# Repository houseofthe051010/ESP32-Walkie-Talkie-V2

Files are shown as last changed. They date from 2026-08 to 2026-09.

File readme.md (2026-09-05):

# ESP32 Walkie Talkie V2

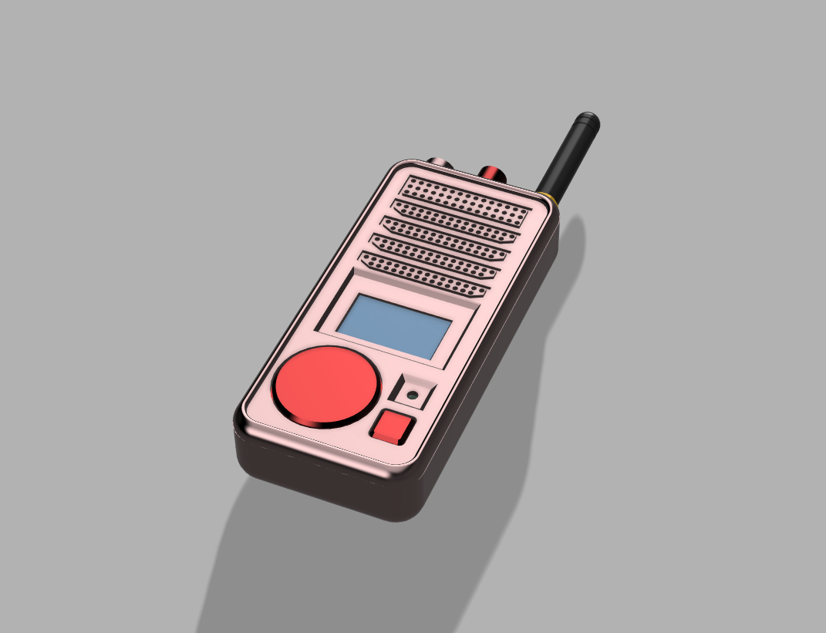
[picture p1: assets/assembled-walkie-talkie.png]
Fully assembled walkie-talkie design


This project is submitted to review at forge; And also, I have made a similar ESP32 based walkie talkie in the past. This is an iteration and is significantly different from the old version. It uses a custom PCB, new and different components, communication protocols, radios, and CAD/casing. It is a much needed iteration from my old version which was very difficult to hard wire and prone to several mistakes.

## Instructions

Build instructions are at: [instructions.md](instructions.md)

## Why this project exists

I made this projet not because I just wanted a walkie talkie, I wanted a control interface for my other projects. Not only can I use this board as a walkie talkie, I can use it in my other projects for other types of communications as the PCB is basically a built in radio system, which I can connect to another system using uart and use it for several other purposes. It has a LORA SX1262 radio, with 5-10km range, but at the same time has a ESP32 with WIFI+BLUETOOTH. I can use this for IoT long distance, and connect wifi/bluetooth devices and extend their range significantly using the radio. This is different from walkie talkies already out there.

## Features

- Can be used for IOT (Wifi + Bluetooth) long distance when paired with the 915mhz radio
- 5 Buttons to do multiple things 
- Exposed pins to connect pheripherals, such as an IMU
- ICS-43432 I2S microphone, MAX98753A amplifier, SSD1306 0.96" OLED, SX1262 RADIO, ESP32WROOM32-16
- Potentiometer, battery charge detection, TP4056 charging, 2000MAH Lipo, 10H batery life

## Hardware

In the Schematics folder is the GERBER+BOM+CPL file for easy PCBA assembly of this board. The KiCad project is also there.

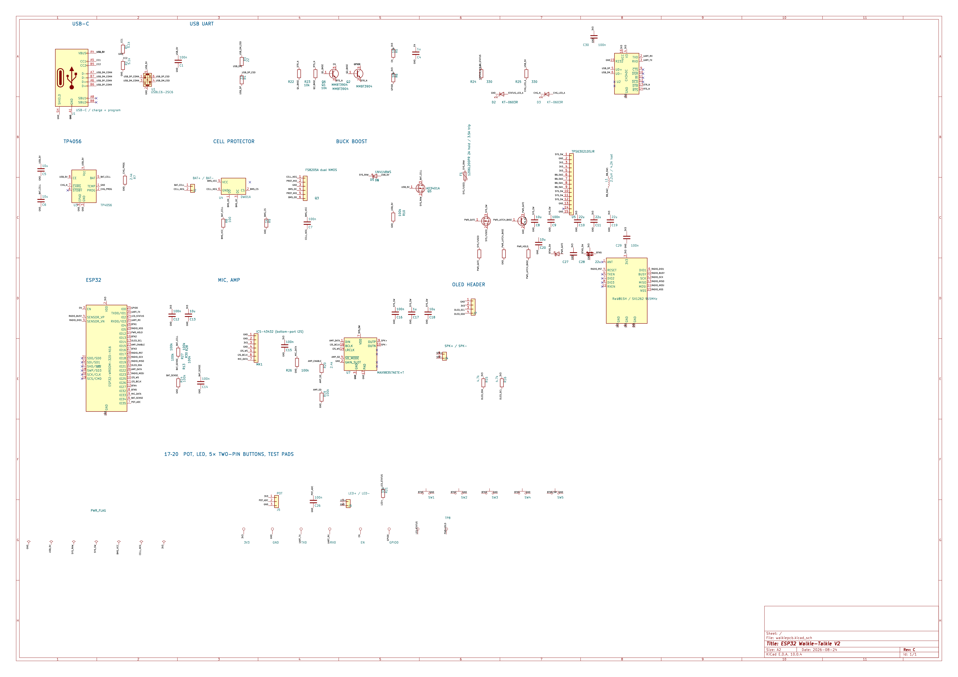
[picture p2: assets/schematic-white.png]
Walkie-talkie schematic


## Firmware

I have included a basic micropython test file for using the walkie talkie when assembled with its radio. It is just a prototype and not complete. I will likely make a full firmware by porting it from my old walkie talkie build and using it as a tempalte.

## Project BOM

| Item | Qty/walkie | Pack | Pack price | Per piece | Cost/walkie | Source / note |
|---|---:|---:|---:|---:|---:|---|
| Assembled walkie-talkie PCB | 1 | 5 | $167.97 | $33.5940 | $33.5940 | [Five-PCBA quote](assets/jlc-quote-5-pcba.png); includes PCB components assembly |
| 0.96-inch SSD1306 I2C OLED | 1 | 5 | $8.83 | $1.7660 | $1.7660 | [AliExpress OLED](https://www.aliexpress.us/item/3256805954920554.html) |
| 804050 2000 mAh 3.7 V LiPo | 1 | 4 | $16.60 | $4.1500 | $4.1500 | [AliExpress battery pack](https://www.aliexpress.us/item/3256812605593313.html)|
| 915 MHz 2 dBi antenna with I-PEX/U.FL lead | 1 | 4 | $5.66 | $1.4150 | $1.4150 | [AliExpress antenna](https://www.aliexpress.us/item/3256805050972049.html)|
| 6 × 6 × 5 mm tactile push button | 5 | 50 | $1.28 | $0.0256 | $0.1280 | [AliExpress button pack](https://www.aliexpress.us/item/3256805859865632.html) |
| 0.5 W ultra-slim speaker | 1 | 5 | $2.43 | $0.4860 | $0.4860 | [AliExpress speaker](https://www.aliexpress.us/item/3256809614775479.html) |
| 20 kΩ panel potentiometer | 1 | 5 | $1.86 | $0.3720 | $0.3720 | [AliExpress potentiometer](https://www.aliexpress.us/item/2255799926052367.html) |
| Printed Casing, Wires, and Screws | 1 Set | 1 | $0 | $0 | $0 | Use available filament, wire and m3 screws or glue. |
| 650 nm 5 mW laser module | 1 | 10 | $2.83 | $0.2830 | $0.2830 | [AliExpress laser module](https://www.aliexpress.us/item/3256806548478140.html) |
| **Complete cost per walkie-talkie** |  |  |  |  | **$42.1940 (~$42.19)** | Per-unit|

### What I would do differently in the future / future plans

- I would make it thinner
- Use more dense parts for smaller size (with a stronger budget)
- Make it fully waterproof

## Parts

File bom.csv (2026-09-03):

Category | Item | Quantity per Walkie | Pack Quantity | Pack Price USD | Price per Piece USD | Cost per Walkie USD | Source URL | Notes
PCB | Assembled walkie-talkie PCB | 1 | 5 | 167.97 | 33.5940 | 33.5940 | assets/jlc-quote-5-pcba.png | Five-PCBA quote includes 163.97 assembly plus 4.00 PCB fabrication; excludes shipping and tax
Display | 0.96-inch SSD1306 I2C OLED module | 1 | 5 | 8.83 | 1.7660 | 1.7660 | https://www.aliexpress.us/item/3256805954920554.html | Verify the ordered variant uses the required four-pin I2C interface and pin order
Power | 804050 2000 mAh 3.7 V 1S LiPo | 1 | 4 | 16.60 | 4.1500 | 4.1500 | https://www.aliexpress.us/item/3256812605593313.html | Verify actual dimensions lead polarity discharge rating and protection before installation
RF | 915 MHz 2 dBi antenna with I-PEX/U.FL lead | 1 | 4 | 5.66 | 1.4150 | 1.4150 | https://www.aliexpress.us/item/3256805050972049.html | Use one antenna per walkie; verify 915 MHz tuning and connector compatibility before transmitting
Controls | 6 x 6 x 5 mm tactile push button | 5 | 50 | 1.28 | 0.0256 | 0.1280 | https://www.aliexpress.us/item/3256805859865632.html | Five buttons required per walkie
Audio | 0.5 W ultra-slim speaker | 1 | 5 | 2.43 | 0.4860 | 0.4860 | https://www.aliexpress.us/item/3256809614775479.html | Verify the purchased impedance is 4-8 ohms and confirm enclosure fit
Controls | 20 kohm panel potentiometer | 1 | 5 | 1.86 | 0.3720 | 0.3720 | https://www.aliexpress.us/item/2255799926052367.html | Connect the ends to 3V3 and GND and the wiper to POT_ADC
Assembly | Printed Casing, Wires, and Screws | 1 Set | 1 | 0 | 0 | 0 |  | Use available filament, wire and m3 screws or glue.
Accessory | 650 nm 5 mW laser module | 1 | 10 | 2.83 | 0.2830 | 0.2830 | https://www.aliexpress.us/item/3256806548478140.html | One laser module per walkie; user-supplied pack price
TOTAL | Complete cost per walkie | 1 | N/A | N/A | N/A | 42.1940 |  | Per-walkie allocated parts cost using the five-PCBA quote; excludes shipping and tax

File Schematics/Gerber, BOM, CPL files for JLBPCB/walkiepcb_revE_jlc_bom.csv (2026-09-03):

Comment | Designator | Footprint | LCSC Part #
100n | C1,C7,C9,C12,C14,C15,C16,C26,C29,C30 | Capacitor_SMD:C_0603_1608Metric | C14663
1u | C4,C17 | Capacitor_SMD:C_0603_1608Metric | C15849
10u | C5,C6,C8,C13,C18,C20 | Capacitor_SMD:C_0805_2012Metric | C15850
22u | C10,C11,C19,C27,C28 | Capacitor_SMD:C_0805_2012Metric | C45783
SS34 | D1 | Diode_SMD:D_SMA | C8678
KT-0603R | D2,D3 | LED_SMD:LED_0603_1608Metric | C2286
1N4148WS | D5,D6 | Diode_SMD:D_SOD-323 | C2128
1206L200PR 2A hold / 3.5A trip | F1 | Fuse:Fuse_1206_3216Metric | C151163
USB-C / charge + program | J1 | Connector_USB:USB_C_Receptacle_HRO_TYPE-C-31-M-12 | C165948
2.2uH / 4.2A Isat | L1 | Inductor_SMD:L_Murata_DFE201610P | C6807735
ICS-43432 (bottom-port I2S) | MK1 | walkiepcb:ICS-43432_LGA7_4x3mm | C574021
MMBT3904 | Q1,Q2,Q6 | Package_TO_SOT_SMD:SOT-23 | C20526
FS8205A dual NMOS | Q3 | Package_TO_SOT_SMD:SOT-23-6 | C908265
AO3401A | Q4,Q5 | Package_TO_SOT_SMD:SOT-23 | C15127
5.1k | R1,R2 | Resistor_SMD:R_0603_1608Metric | C23186
22 | R3,R4 | Resistor_SMD:R_0603_1608Metric | C23345
10k | R5,R6,R22,R23 | Resistor_SMD:R_0603_1608Metric | C25804
2.4k | R7,R20 | Resistor_SMD:R_0603_1608Metric | C22940
100 | R8 | Resistor_SMD:R_0603_1608Metric | C22775
1k | R9 | Resistor_SMD:R_0603_1608Metric | C21190
100k | R10,R13,R14,R19 | Resistor_SMD:R_0603_1608Metric | C25803
4.7k | R15,R16 | Resistor_SMD:R_0603_1608Metric | C23162
330 | R21,R24,R25 | Resistor_SMD:R_0603_1608Metric | C23138
100k | R26,R27,R28,R30 | Resistor_SMD:R_0402_1005Metric | C25741
USBLC6-2SC6 | U1 | Package_TO_SOT_SMD:SOT-23-6 | C7519
CH340C | U2 | Package_SO:SOIC-16_3.9x9.9mm_P1.27mm | C7464026
TP4056-42-ESOP8 | U3 | Package_SO:SOIC-8-1EP_3.9x4.9mm_P1.27mm_EP2.41x3.3mm | C16581
DW01A | U4 | Package_TO_SOT_SMD:SOT-23-6 | C351410
TPS63021DSJR | U5 | Package_DFN_QFN:DFN-14-1EP_3x4mm_P0.5mm_EP1.7x3.3mm | C202140
ESP32-WROOM-32D-N16 | U6 | RF_Module:ESP32-WROOM-32 | C529578
MAX98357AETE+T | U7 | Package_DFN_QFN:TQFN-16-1EP_3x3mm_P0.5mm_EP1.23x1.23mm | C910544
Ra-01SH / SX1262 915MHz | U8 | walkiepcb:Ai-Thinker_Ra-01SH | C2764087

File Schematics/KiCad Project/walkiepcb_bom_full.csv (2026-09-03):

Reference | Value | Footprint | Manufacturer | MPN | JLC/LCSC | JLC Classification | Economic Compatible | DNP | Notes | QUANTITY
C1,C7,C9,C12,C14-C16,C26,C29,C30 | 100n | Capacitor_SMD:C_0603_1608Metric | YAGEO | CC0603KRX7R9BB104 | C14663 | Basic | YES | NO | ADC acquisition reservoir; 5ms Thevenin RC,Buck-boost VINA bypass; place at VINA/GND,Connector-local VBUS bypass,DW01 supply filter,ESP32 local HF bypass,ICS-43432 local bypass; place directly between VDD and GND,MAX98357A local bypass,Potentiometer ADC filter,Ra-01SH/CH340C local high-frequency decoupling | 10
C4,C17 | 1u | Capacitor_SMD:C_0603_1608Metric | Samsung Electro-Mechanics | CL10A105KB8NNNC | C15849 | Basic | YES | NO | ESP32 EN power-on delay,MAX98357A local mid-band bypass | 2
C5,C6,C8,C13,C18,C20 | 10u | Capacitor_SMD:C_0805_2012Metric | Samsung Electro-Mechanics | CL21A106KAYNNNE | C15850 | Basic | YES | NO | Buck-boost input capacitor 2; TPS63021 reference design uses 2x10uF at VIN/PGND,Buck-boost input capacitor; place at VIN/PGND,ESP32 local bulk,MAX98357A local bulk,TP4056 battery bypass,TP4056 input bulk | 6
C10,C11,C19,C27,C28 | 22u | Capacitor_SMD:C_0805_2012Metric | Samsung Electro-Mechanics | CL21A226MAQNNNE | C45783 | Basic | YES | NO | Ra-01SH local bulk decoupling,TPS63021 output capacitor 1; place at VOUT/PGND,TPS63021 output capacitor 2; place at VOUT/PGND,TPS63021 output capacitor 3; 66uF nominal bank follows TI stability matrix | 5
D1 | SS34 | Diode_SMD:D_SMA | MDD | SS34 | C8678 | Basic | YES | NO | USB-to-system Schottky; anode USB, cathode SYS_RAW | 1
D2,D3 | KT-0603R | LED_SMD:LED_0603_1608Metric | Hubei KENTO | KT-0603R | C2286 | Basic | YES | NO | On-board status LED,TP4056 charging indicator; on while charging | 2
D5,D6 | 1N4148WS | Diode_SMD:D_SOD-323 | Jiangsu Changjing Electronics Technology | 1N4148WS | C2128 | Basic | YES | NO | BTN5 sense diode; A=BTN5 K=BTN5_SW,BTN5 start diode; A=PWR_GATE K=BTN5_SW | 2
F1 | 1206L200PR 2A hold / 3.5A trip | Fuse:Fuse_1206_3216Metric | Littelfuse | 1206L200PR | C151163 | Extended | YES | NO | Resettable system fault protection | 1
J1 | USB-C / charge + program | Connector_USB:USB_C_Receptacle_HRO_TYPE-C-31-M-12 | Korean Hroparts Elec | TYPE-C-31-M-12 | C165948 | Extended | YES | NO | USB 2.0 sink; shell grounded | 1
J2 | BAT+ / BAT- | walkiepcb:WirePads_2_P5.08mm | Hand-wired | 2 solder pads |  | DNP | YES | YES | Battery wires; BAT- is cell negative before protection FETs | 1
J4 | SPK+ / SPK- | walkiepcb:WirePads_2_P5.08mm | Hand-wired | 2 solder pads |  | DNP | YES | YES | Differential Class-D output; neither terminal is ground | 1
J5 | 3V3 / POT_ADC / GND | walkiepcb:WirePads_3_P2.54mm | Hand-wired | 3 solder pads |  | DNP | YES | YES | External potentiometer; exactly three holes | 1
J6 | LED+ / LED- | walkiepcb:WirePads_2_P2.54mm | Hand-wired | 2 solder pads |  | DNP | YES | YES | External LED; exactly two holes | 1
J7 | OLED MODULE: GND / 3V3 / SCL / SDA | walkiepcb:OLED_1x04_P2.54mm_HolesOnly | Hand-wired | 2.54mm 1x4 header |  | DNP | YES | YES | For a commercial SSD1306 I2C module; verify the module pin order before wiring | 1
L1 | 2.2uH / 4.2A Isat | Inductor_SMD:L_Murata_DFE201610P | Sunlord | MWTC201610S2R2MT | C6807735 | Extended | YES | NO | 123mohm; 2.3A Irms; 4.2A Isat; buck-boost energy-transfer inductor | 1
MK1 | ICS-43432 (bottom-port I2S) | walkiepcb:ICS-43432_LGA7_4x3mm | TDK InvenSense | ICS-43432 | C574021 | Extended | YES | NO | Economic-compatible but high-difficulty assembly; stocked bottom-port I2S microphone | 1
Q1,Q2,Q6 | MMBT3904 | Package_TO_SOT_SMD:SOT-23 | CJ (Changjiang Electronics Tech) | MMBT3904 | C20526 | Basic | YES | NO | CH340C DTR/RTS automatic-programming transistor,Firmware-controlled main-gate pull-down | 3
Q3 | FS8205A dual NMOS | Package_TO_SOT_SMD:SOT-23-6 | FUXINSEMI | FS8205A | C908265 | Extended | YES | NO | Back-to-back common-drain battery-protection MOSFET; verified FUXINSEMI pinout | 1
Q4,Q5 | AO3401A | Package_TO_SOT_SMD:SOT-23 | Alpha & Omega Semiconductor | AO3401A | C15127 | Basic | YES | NO | Main soft-power high-side P-MOSFET; S=SYS_FUSED D=SYS_SW,P-channel ideal battery path; S=SYS_RAW D=BAT_CELL | 2
R1,R2 | 5.1k | Resistor_SMD:R_0603_1608Metric | UNI-ROYAL | 0603WAF5101T5E | C23186 | Basic | YES | NO | USB-C Rd | 2
R3,R4 | 22 | Resistor_SMD:R_0603_1608Metric | UNI-ROYAL | 0603WAF220JT5E | C23345 | Basic | YES | NO | USB D+ series termination; place near CH340C,USB D- series termination; place near CH340C | 2
R5,R6,R22,R23 | 10k | Resistor_SMD:R_0603_1608Metric | UNI-ROYAL | 0603WAF1002T5E | C25804 | Basic | YES | NO | CH340C automatic-programming transistor base resistor,ESP32 EN pull-up,ESP32 boot pull-up | 4
R7,R20 | 2.4k | Resistor_SMD:R_0603_1608Metric | UNI-ROYAL | 0603WAF2401T5E | C22940 | Basic | YES | NO | Limits SD_MODE clamp current if raw VDD falls below 3V3,Sets TP4056 current ≈500mA | 2
R8 | 100 | Resistor_SMD:R_0603_1608Metric | UNI-ROYAL | 0603WAF1000T5E | C22775 | Basic | YES | NO | DW01 supply filter | 1
R9 | 1k | Resistor_SMD:R_0603_1608Metric | UNI-ROYAL | 0603WAF1001T5E | C21190 | Basic | YES | NO | DW01 current-sense input filter | 1
R10,R13,R14,R19 | 100k | Resistor_SMD:R_0603_1608Metric | UNI-ROYAL | 0603WAF1003T5E | C25803 | Basic | YES | NO | Battery divider lower,Battery divider upper,Keeps amplifier shut down during boot,PMOS gate pull-down | 4
R15,R16 | 4.7k | Resistor_SMD:R_0603_1608Metric | UNI-ROYAL | 0603WAF4701T5E | C23162 | Basic | YES | NO | I2C pull-up | 2
R21,R24,R25 | 330 | Resistor_SMD:R_0603_1608Metric | UNI-ROYAL | 0603WAF3300T5E | C23138 | Basic | YES | NO | Indicator current limit; reuses existing Basic BOM line,≈3.9mA for 2.0V LED at 3.3V | 3
R26-R28,R30 | 100k | Resistor_SMD:R_0402_1005Metric | UNI-ROYAL | 0402WGF1003TCE | C25741 | Basic | YES | NO | GPIO12 hold base-current limit,ICS-43432 SD pulldown required while microphone output is tri-stated,Latch-transistor base pull-down,Main P-MOS gate pull-up | 4
SW1 | BTN1 / hand-solder | walkiepcb:SW_Tactile_2Pin_6x6mm_P5.0mm | E-Switch or equivalent | TL1100F100QG |  | DNP | YES | YES | Exactly two plated holes; ESP32 internal pull-up | 1
SW2 | BTN2 / hand-solder | walkiepcb:SW_Tactile_2Pin_6x6mm_P5.0mm | E-Switch or equivalent | TL1100F100QG |  | DNP | YES | YES | Exactly two plated holes; ESP32 internal pull-up | 1
SW3 | BTN3 / hand-solder | walkiepcb:SW_Tactile_2Pin_6x6mm_P5.0mm | E-Switch or equivalent | TL1100F100QG |  | DNP | YES | YES | Exactly two plated holes; ESP32 internal pull-up | 1
SW4 | BTN4 / hand-solder | walkiepcb:SW_Tactile_2Pin_6x6mm_P5.0mm | E-Switch or equivalent | TL1100F100QG |  | DNP | YES | YES | Exactly two plated holes; ESP32 internal pull-up | 1
SW5 | BTN5 POWER / FUNCTION | walkiepcb:SW_Tactile_2Pin_6x6mm_P5.0mm | E-Switch or equivalent | TL1100F100QG |  | DNP | YES | YES | Hold 2 s for firmware-validated power on/off; pulls PWR_GATE low | 1
TP1 | 3V3 | walkiepcb:TestPad_1.0mm | PCB pad | SMD test pad |  | PCB | YES | YES | Probe-only test pad | 1
TP2 | GND | walkiepcb:TestPad_1.0mm | PCB pad | SMD test pad |  | PCB | YES | YES | Probe-only test pad | 1
TP3 | TX0 | walkiepcb:TestPad_1.0mm | PCB pad | SMD test pad |  | PCB | YES | YES | Probe-only test pad | 1
TP4 | RX0 | walkiepcb:TestPad_1.0mm | PCB pad | SMD test pad |  | PCB | YES | YES | Probe-only test pad | 1
TP5 | EN | walkiepcb:TestPad_1.0mm | PCB pad | SMD test pad |  | PCB | YES | YES | Probe-only test pad | 1
TP6 | GPIO0 | walkiepcb:TestPad_1.0mm | PCB pad | SMD test pad |  | PCB | YES | YES | Probe-only test pad | 1
TP7 | LED_STATUS | walkiepcb:TestPad_1.0mm | PCB pad | SMD test pad |  | PCB | YES | YES | Optional expansion solder/test pad | 1
TP8 | PWR_HOLD / GPIO12 | walkiepcb:TestPad_1.0mm | PCB pad | SMD test pad |  | PCB | YES | YES | Soft-power hold output and diagnostic pad; GPIO12 boot strap | 1
U1 | USBLC6-2SC6 | Package_TO_SOT_SMD:SOT-23-6 | STMicroelectronics | USBLC6-2SC6 | C7519 | Extended | YES | NO | Low-capacitance USB ESD | 1
U2 | CH340C | Package_SO:SOIC-16_3.9x9.9mm_P1.27mm | WCH | CH340C | C7464026 | Extended | YES | NO | Crystal-less USB-UART; VCC and V3 tied to switched 3V3; main switch must be ON for USB programming | 1
U3 | TP4056-42-ESOP8 | Package_SO:SOIC-8-1EP_3.9x4.9mm_P1.27mm_EP2.41x3.3mm | Top Power ASIC | TP4056-42-ESOP8 | C16581 | Extended | YES | NO | RPROG 2.4k gives nominal 500mA; EP grounded | 1
U4 | DW01A | Package_TO_SOT_SMD:SOT-23-6 | PUOLOP | DW01A | C351410 | Extended | YES | NO | 1S protector; 4.3V overcharge / 2.5V overdischarge; deep-discharge cutoff is safety backup | 1
U5 | TPS63021DSJR | Package_DFN_QFN:DFN-14-1EP_3x4mm_P0.5mm_EP1.7x3.3mm | Texas Instruments | TPS63021DSJR | C202140 | Extended | YES | NO | Fixed 3.3V synchronous buck-boost; pin15 models exposed PGND pad; PS/SYNC low = power-save; EN tied VIN | 1
U6 | ESP32-WROOM-32D-N16 | RF_Module:ESP32-WROOM-32 | Espressif Systems | ESP32-WROOM-32D-N16 | C529578 | Extended | YES | NO | 16MB flash; PCB antenna; CH340C UART programming | 1
U7 | MAX98357AETE+T | Package_DFN_QFN:TQFN-16-1EP_3x3mm_P0.5mm_EP1.23x1.23mm | Analog Devices / Maxim | MAX98357AETE+T | C910544 | Extended | YES | NO | 12dB fixed gain; left channel; EP grounded | 1
U8 | Ra-01SH / SX1262 915MHz | walkiepcb:Ai-Thinker_Ra-01SH | Ai-Thinker | Ra-01SH | C2764087 | Extended | YES | NO | SX1262; 803-930MHz; integrated I-PEX socket; +22dBm | 1

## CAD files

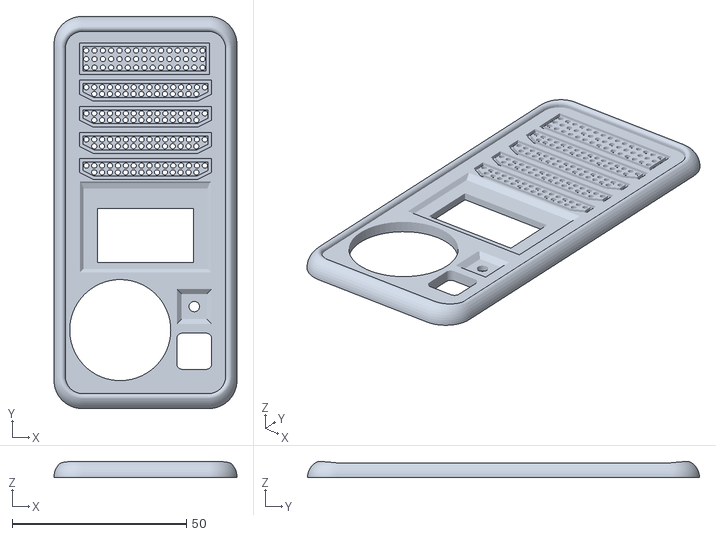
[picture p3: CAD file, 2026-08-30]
CAD/3d Printable STLs/Case Lid.stl
52.5 x 112.5 x 4.66

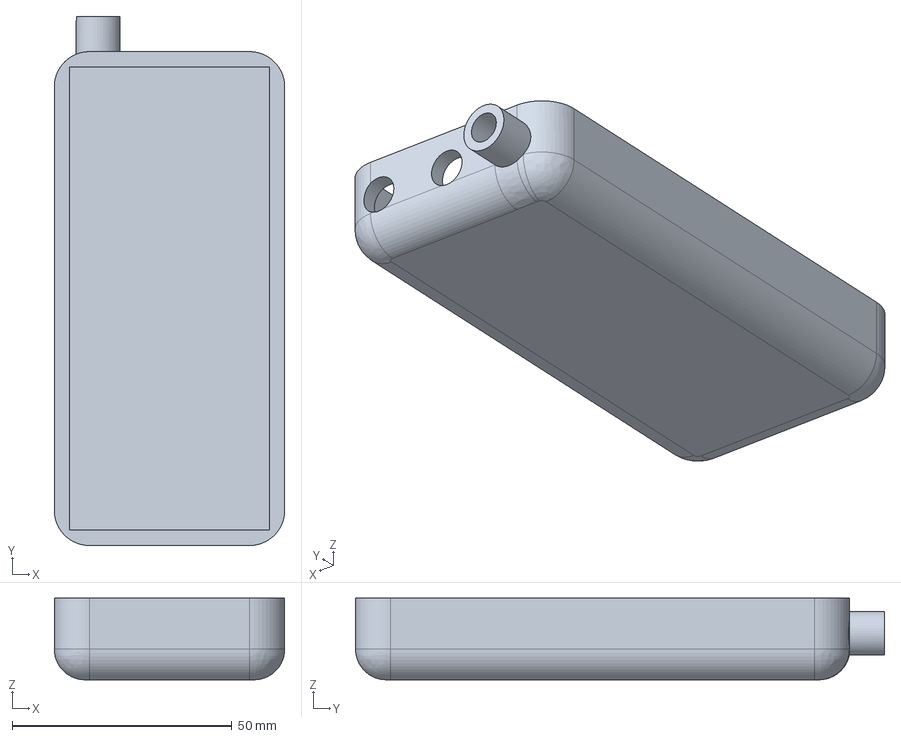
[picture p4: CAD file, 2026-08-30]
CAD/Individual STEP Files/Case Bottom.step
52.5 x 120.5 x 18.6 mm

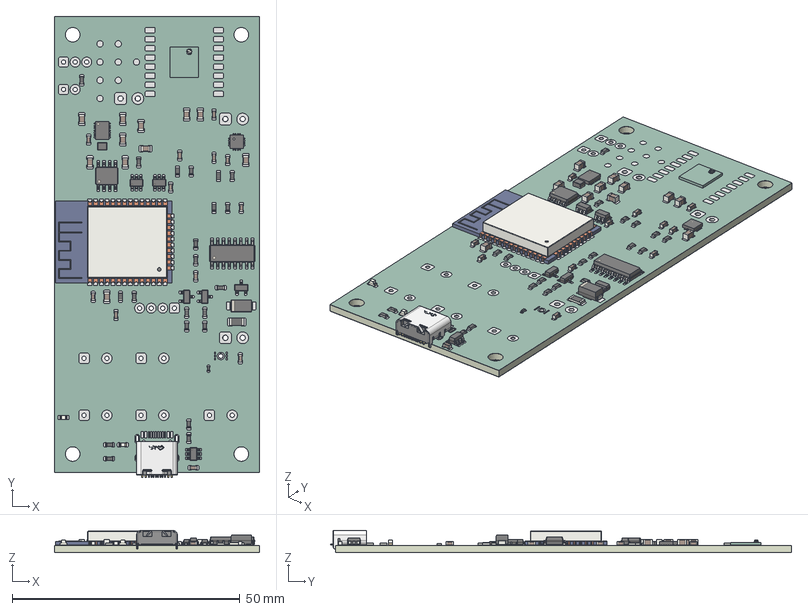
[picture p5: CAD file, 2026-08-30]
CAD/PCB/walkiepcb_final.step
45.0 x 101.1 x 4.90 mm
R_0603_1608Metric x 21
SOT-23 x 3
C_0603_1608Metric x 12
ESP32-WROOM-32
L_Murata_DFE201610P
SOT-23-6 x 3
Fuse_1206_3216Metric
LED_0603_1608Metric x 2
C_0805_2012Metric x 11
D_SMA
SOIC-16_3.9x9.9mm_P1.27mm
USB-C_SMD-TYPE-C-31-M-12
R_0402_1005Metric
U.FL_Hirose_U.FL-R-SMT-1_Vertical
Ra-01SH_step_source_PCB
SOIC-8-1EP_3.9x4.9mm_P1.27mm_EP2.41x3.81mm
TQFN_16_1EP_3x3mm_P05mm_EP16x16mm
DFN-14-1EP_3x4mm_Pitch0.5mm
walkiepcb_step_export_copper
walkiepcb_step_export_pad
walkiepcb_step_export_via
walkiepcb_step_export_soldermask x 2
walkiepcb_step_export_PCB

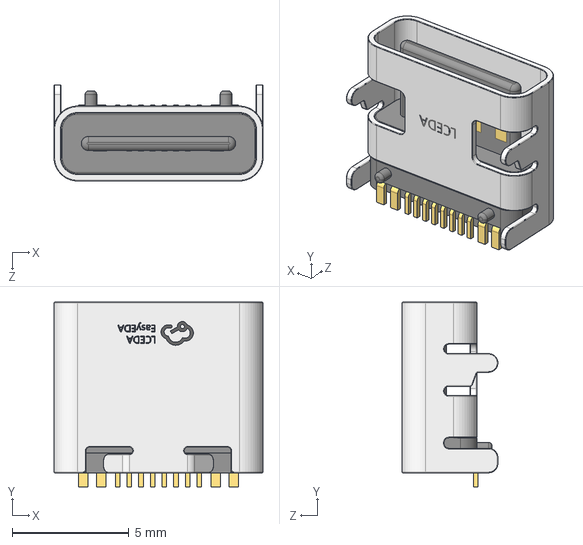
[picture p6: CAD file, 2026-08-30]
Schematics/KiCad Project/3d/USB-C_SMD-TYPE-C-31-M-12.step
8.94 x 7.90 x 4.10 mm

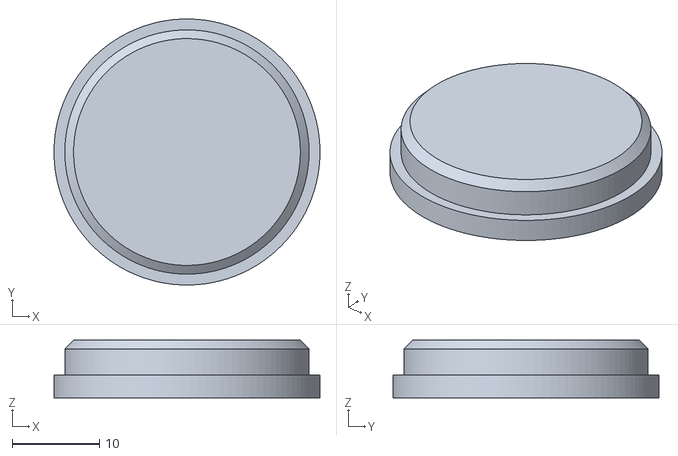
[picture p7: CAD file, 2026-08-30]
CAD/3d Printable STLs/Button Pad.stl
30.5 x 30.5 x 6.60

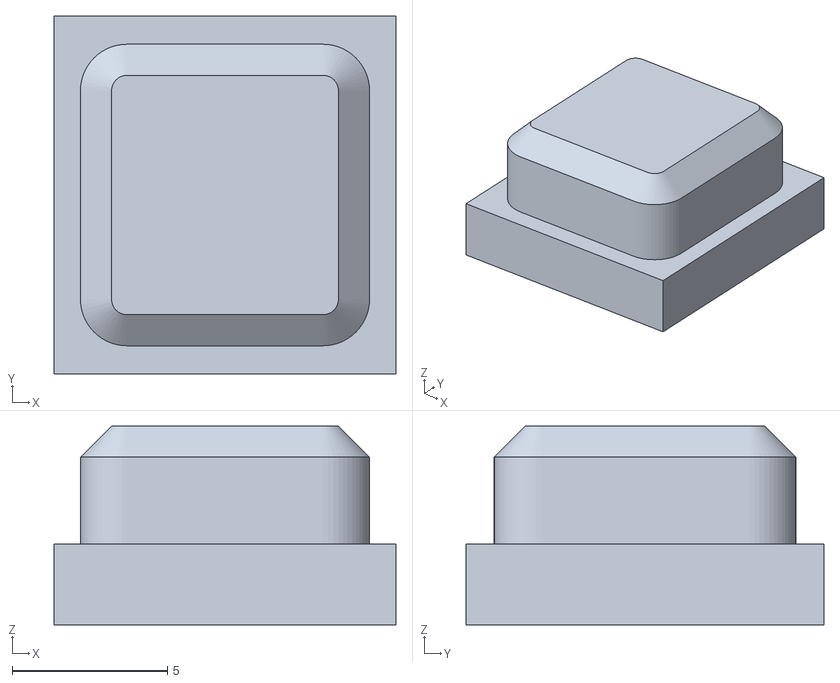
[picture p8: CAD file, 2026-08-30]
CAD/3d Printable STLs/Button Press.stl
11.0 x 11.5 x 6.40

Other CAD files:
CAD/Assembly/Walkie Talkie V2.step
CAD/3d Printable STLs/Case Bottom.stl
CAD/Individual STEP Files/Case Lid.step
CAD/Individual STEP Files/Button Pad.step
CAD/Individual STEP Files/Button Press.step
CAD/Assembly/Walkie Talkie V2 PCB.f3z

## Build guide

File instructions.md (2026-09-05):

# Walkie Talkie Instructions

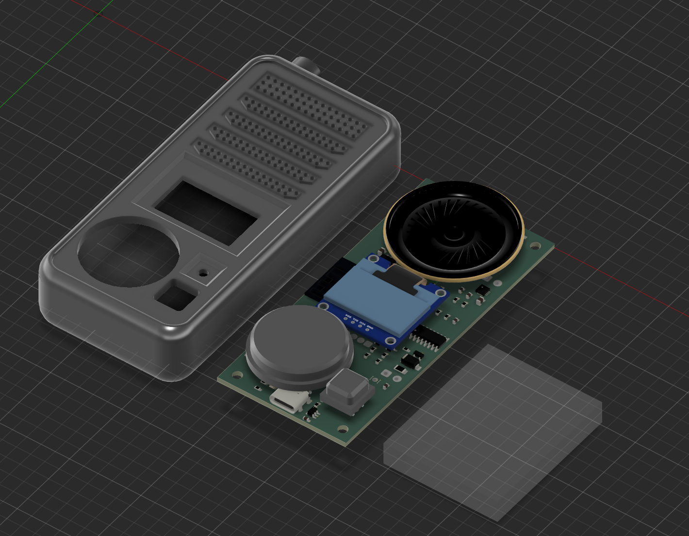
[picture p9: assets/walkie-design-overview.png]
Walkie-talkie enclosure and PCB design


1. You must get the lipo battery and solder its wires to the input of the pcb

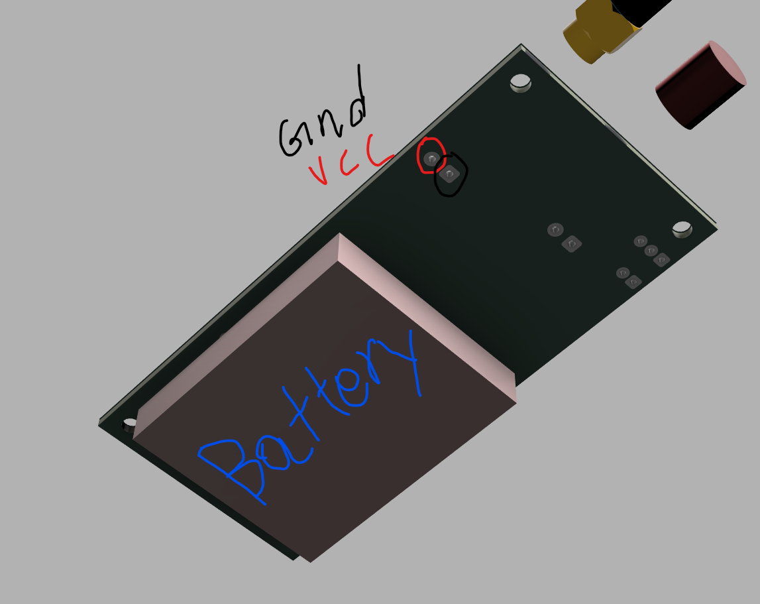
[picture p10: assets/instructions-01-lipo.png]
Lipo battery connected to the PCB


2. Then, solder all 5 buttons using the through holes in the pcb

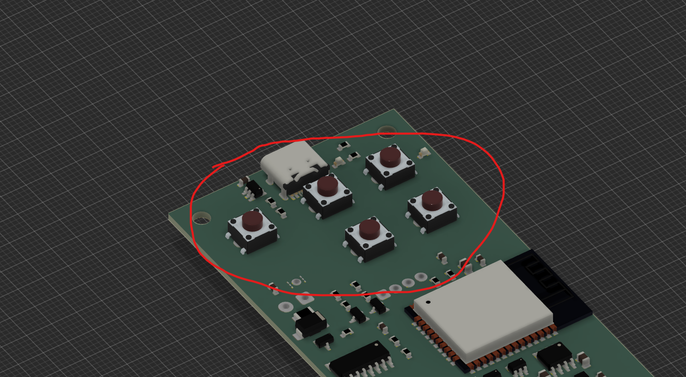
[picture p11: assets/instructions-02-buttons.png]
Five buttons soldered to the PCB


3. Next, solder on the OLED display through the 4 pin slot

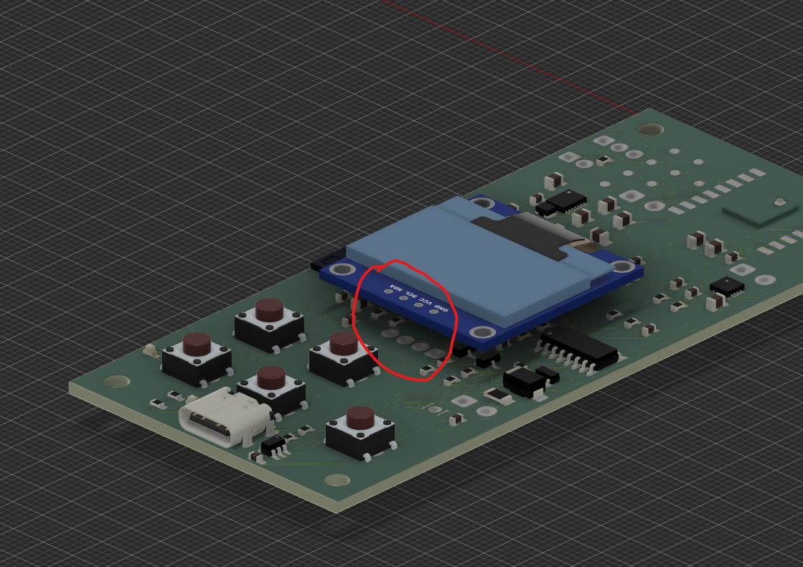
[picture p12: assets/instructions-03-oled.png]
OLED display connected through the four-pin slot


4. Next, solder on the potentiometer looking at the diagram below

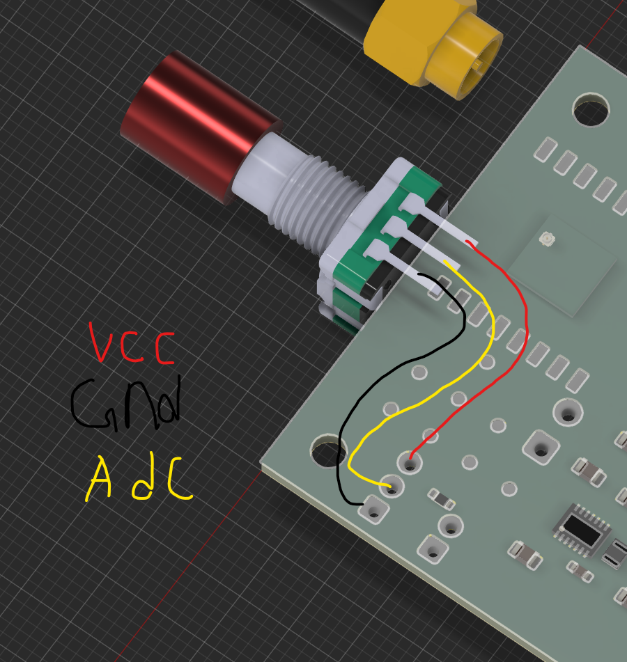
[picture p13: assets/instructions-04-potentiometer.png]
Potentiometer wiring diagram


5. Print the button pad, and button press stls, and put them as shown in the picture on top of the buttons 

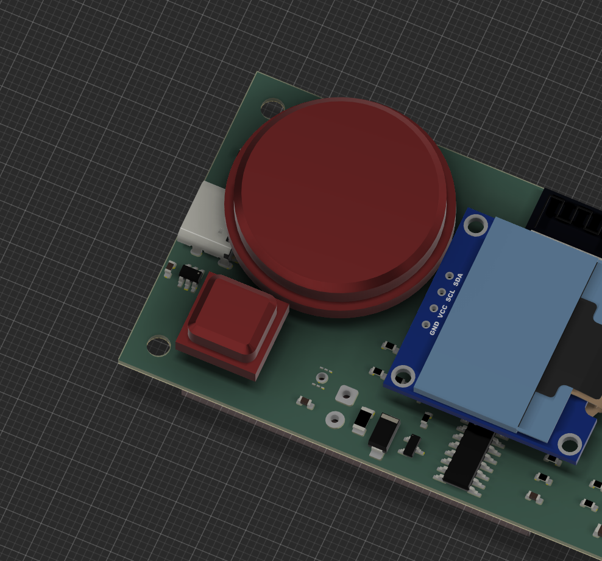
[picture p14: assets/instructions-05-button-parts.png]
Button pad and button press parts


6. Print the case bottom stl and put everything on there. Use a UFL connector with the SX1262 to connect to the radio antenna

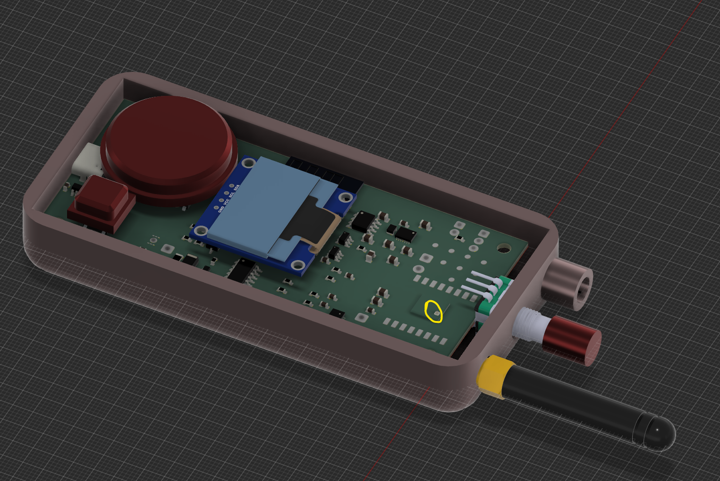
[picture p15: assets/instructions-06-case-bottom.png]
PCB installed in the case bottom with antenna connection


7. Print the case lid and use super glue to add it on

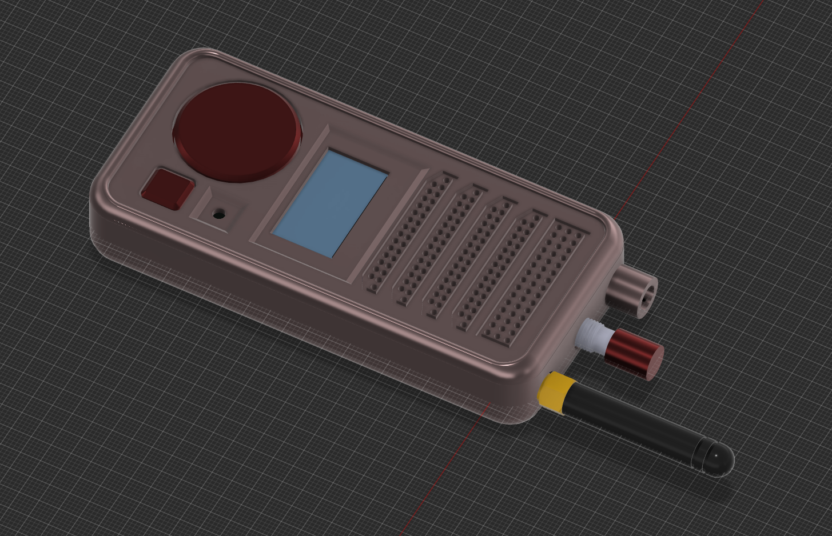
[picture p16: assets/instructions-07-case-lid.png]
Completed case with lid


## Firmware

1. Connect to the esp32 using its usb port to your computer
2. Open thonny editor, download main.py code, and open thonny with it. 
3. Connect to esp32 in thonny using your corresponding COM port
4. Flash micropython onto the esp32
5. Run and save the code onto the esp32

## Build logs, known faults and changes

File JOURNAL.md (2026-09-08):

---
title: "ESP32 Walkie Talkie With SX1262 Radio"
author: "Aditya Verma"
description: "An ESP32 walkie talkie with a custom PCB and SX1262 radio"
created_at: "2026-08-24"
---

# 2026-08-24 - Evaluating Project Goals

**Date: 2026-08-24**

**Time: 1:24 PM**

Time to brainstorm my PCB. I recently created a PCB for this project but that was because my previous SHIP guy rejected it and told me to make a PCB for it. I followed the directions and made a PCB but it was very bad and not optimal. My original design was meant to be hard soldered.

Now, I want to redesign my walkie talkie and do a PCB-FIRST design, where I first design a PCB for my walkie talkie and then build the case around it, which is much easier than soldering messy wires like in my previous version.

Earlier this year, I made a walkie talkie using an esp32, a INMP441 mic, MAX9857A amp, I2C OLED 0.96", buttons, pot, led. It used ESPNOW, but it wasn't the best. It was hardwired, messy (extremely messy and hard to solder) and a PCB version was warranted.

I didn't just want to make a PCB for it. I needed to redesign it. I needed to add an actual radio. In the beginning of my esp32 walkie talkie project, I removed a radio because it got way too hard to solder and space was limited, but my new PCB will have space for a radio. It will feature little wires and be much better.

Here is how the old version was:

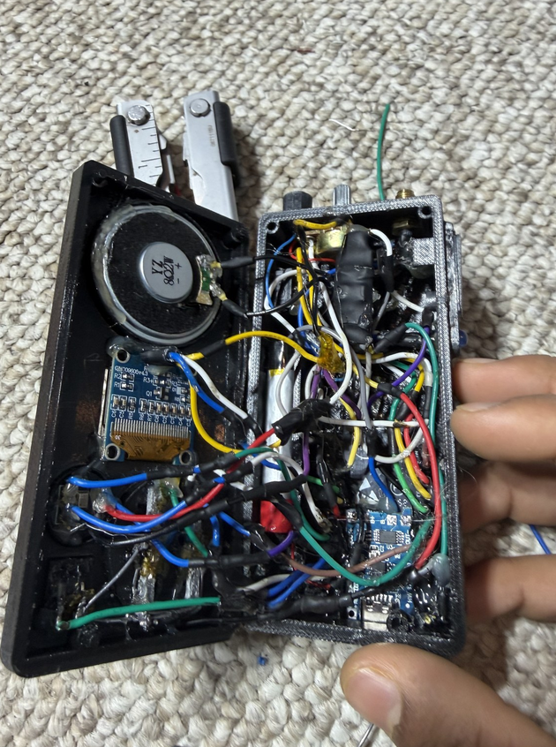
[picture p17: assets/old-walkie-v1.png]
The old version


This is the 2nd iteration I made with thinner wires:

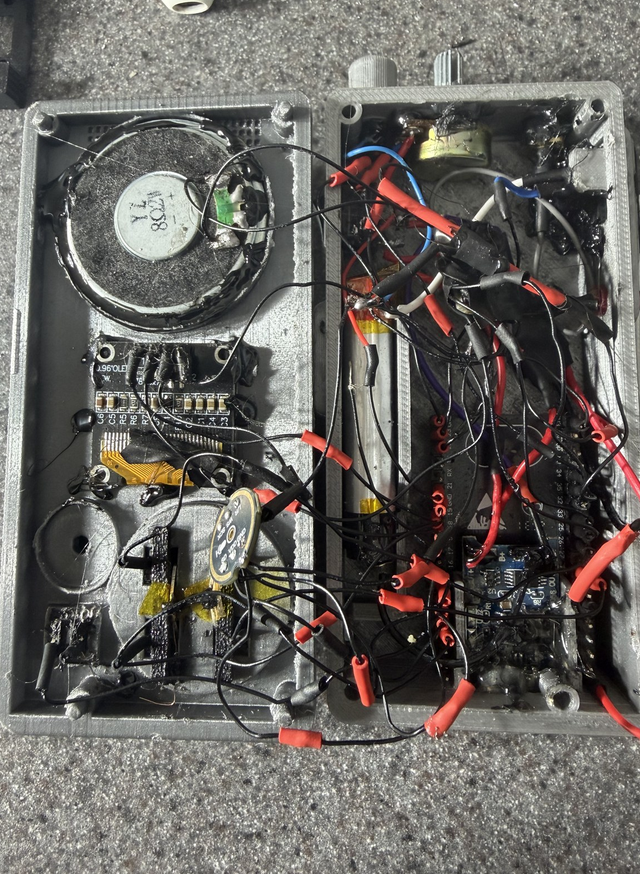
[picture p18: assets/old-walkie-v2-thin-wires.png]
The 2nd iteration with thinner wires


Now, I need to make a PCB, and redesign NEW cad casing around that pcb.

First, I had to choose what I'll use:

I researched, and found out about JLBPCB extended and basic parts. Extended parts costed around 3 dollar tooling fee. Basic didn't have a tooling fee. After learning this, I realized I should maximize basic parts. I went on a searching spree.

What radio was I going to use? I searched up a list of radios and evaluated them. In the end I choose a LORA sx1262 because it was cheap and long range.

Here is the table of radios:

| Radio | Frequency | Modulation |
|---|---|---|
| NRF24L01 | 2.4 GHz | GFSK |
| SX1262 | 150–960 MHz | LoRa, FSK, GFSK |
| SX1280 | 2.4 GHz | LoRa, FLRC, FSK, GFSK |
| CC1101 | 300–348 MHz, 387–464 MHz, 779–928 MHz | FSK, GFSK, MSK, ASK, OOK |

The only worry with my choice was that the 5DBI antenna was 20CM long, which is very long. A shorter 6cm 2dbi antenna was available too but with lower power.

For my MCU, I was going to go with ESP32 S3. It had built in USB and didn't require a UART converter. For my buttons, I was going to remove the PTT system. For the power stage, I was thinking of using a AP7361C 3.2 V LDO.

I was most likely going to be using JLBPCBA so it comes assembled.

**Total time spent: 1.5 hours**

# 2026-08-25 - Starting the Schematic and PCB (6.5 hours)

**Date: 2026-08-25**

**Time: 7:42 PM**

Time to start working on the project. My first step was to figure out what parts I wanted from JLBPCB. I looked through the parts list and decided this BOM:

- ESP32-S3-WROOM-1U-N4
- USB-C connector
- USBLC6-2SC6
- TP4056 charger
- DW01A battery protector
- FS8205A dual MOSFET
- TPS63021 buck-boost
- 2.2uH inductor
- ICS-43432 microphone
- MAX98357A amplifier
- OLED 0.96 SSD1306
- Five buttons
- Potentiometer
- Speaker
- LiPo battery

I spent a while making the schematic.

This is the schematic that I made:

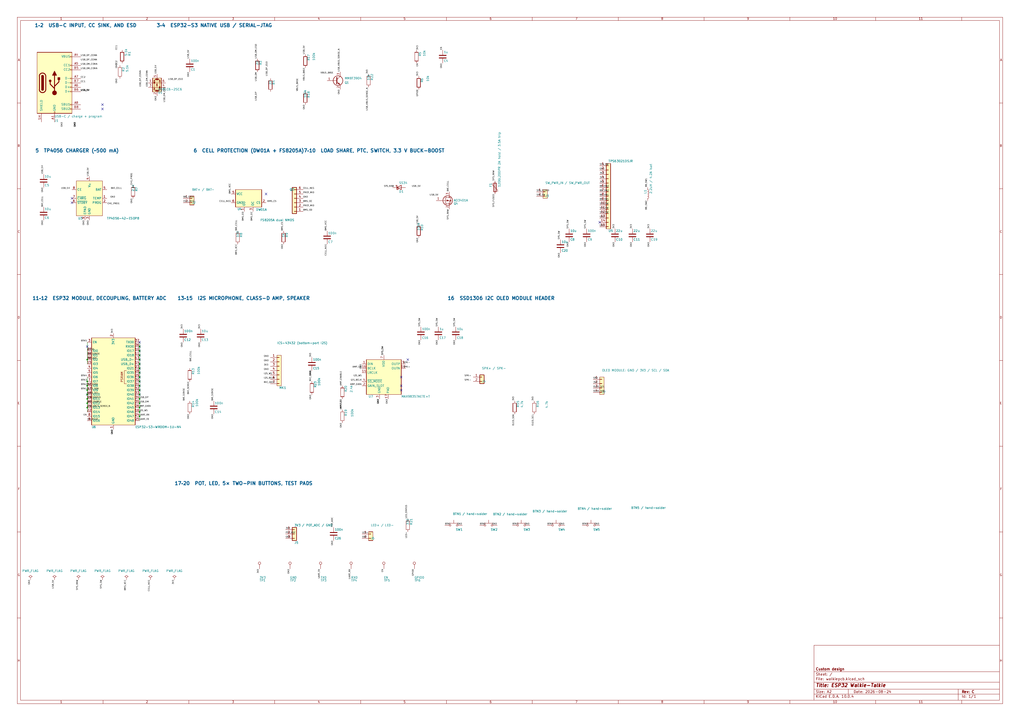
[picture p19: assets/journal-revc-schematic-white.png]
Revision C schematic on a white background


Here is what I was thinking when making the pcb:

Here is the BOM:

| Reference | Quantity | Part | Part number | JLC/LCSC number |
|---|---:|---|---|---|
| C1,C7,C9,C12,C14,C15,C16,C26 | 8 | 100n | CC0603KRX7R9BB104 | C14663 |
| C10,C11,C19 | 3 | 22u | CL21A226MAQNNNE | C45783 |
| C4,C17 | 2 | 1u | CL10A105KB8NNNC | C15849 |
| C5,C6,C8,C20,C13,C18 | 6 | 10u | CL21A106KAYNNNE | C15850 |
| D1 | 1 | SS34 | SS34 | C8678 |
| F1 | 1 | 1206L200PR 2A hold / 3.5A trip | 1206L200PR | C151163 |
| J1 | 1 | USB-C / charge + program | TYPE-C-31-M-12 | C165948 |
| L1 | 1 | 2.2uH / 4.2A Isat | MWTC201610S2R2MT | C6807735 |
| MK1 | 1 | ICS-43432 (bottom-port I2S) | ICS-43432 | C574021 |
| Q1 | 1 | MMBT3904 | MMBT3904 | C20526 |
| Q3 | 1 | FS8205A dual NMOS | FS8205A | C908265 |
| Q4 | 1 | AO3401A | AO3401A | C15127 |
| R1,R2 | 2 | 5.1k | 0603WAF5101T5E | C23186 |
| R15,R16 | 2 | 4.7k | 0603WAF4701T5E | C23162 |
| R17,R18,R10,R13,R14,R23,R19 | 7 | 100k | 0603WAF1003T5E | C25803 |
| R21 | 1 | 330 | 0603WAF3300T5E | C23138 |
| R3,R4 | 2 | 22 | 0603WAF220JT5E | C23345 |
| R5,R6,R22 | 3 | 10k | 0603WAF1002T5E | C25804 |
| R7,R20 | 2 | 2.4k | 0603WAF2401T5E | C22940 |
| R8 | 1 | 100 | 0603WAF1000T5E | C22775 |
| R9 | 1 | 1k | 0603WAF1001T5E | C21190 |
| U1 | 1 | USBLC6-2SC6 | USBLC6-2SC6 | C7519 |
| U3 | 1 | TP4056-42-ESOP8 | TP4056-42-ESOP8 | C16581 |
| U4 | 1 | DW01A | DW01A | C351410 |
| U5 | 1 | TPS63021DSJR | TPS63021DSJR | C202140 |
| U6 | 1 | ESP32-S3-WROOM-1U-N4 | ESP32-S3-WROOM-1U-N4 | C2980296 |
| U7 | 1 | MAX98357AETE+T | MAX98357AETE+T | C910544 |

The ESP32 s3 was necessary and I used the USB lines to avoid the power stage. I had a pinout for a commercial SSD1306 that jlbpcb would solder. I also had resistor circuit for battery measurement. The USB C had power connecting directly to the S3 usb pins. The 5.1k resistors were for the USB. I have a protection for the data lines from electrostatic charge. And resistors to reduce ringing on the pcb. The native USB eliminates the use of a UART converter which lowers my jlbpcb price. And the TP5046 is for charging my lipo at 500ma. My microphone is actually an ICS 43432 unlike the old INMP441. But my AMP is the same MAX98375a. I also am going to have commercial pins for my SSD1306. I have pads for 5 buttons, 3 for a pot, and 2 for an led. 

Now, for the PCB, I was thinking of 45x100 mm. This was smaller than my current board but matched what I wanted with the button layout. In this new walkie talkie design, I removed the side PTT button and the LED because It was unncessary and added to the load. So what I did was used the top 5 buttons which were better and easier to build. This layout was referenced from my old walkie talkie.

My schematic used 5 through hole solder pads for the 5 buttons.

Here is a pic of my PCB I made:

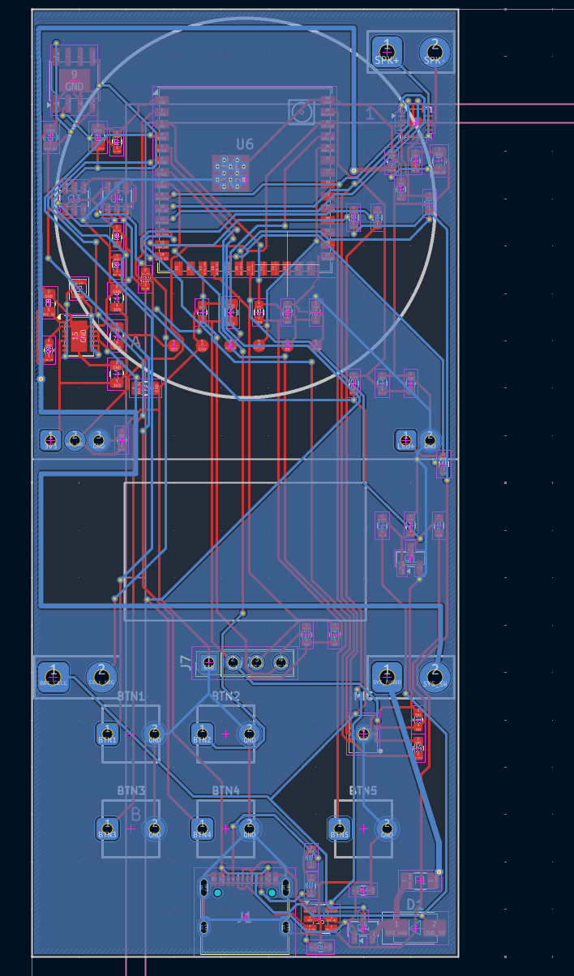
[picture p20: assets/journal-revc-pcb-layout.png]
Revision C PCB layout


I had made the pcb and I was going off my original CAD. The oled stayed in the center, and the speaker was the same, so I sketched some lines for them to give them ample space. I had a single usb c.

This was a picture of the rendered design:

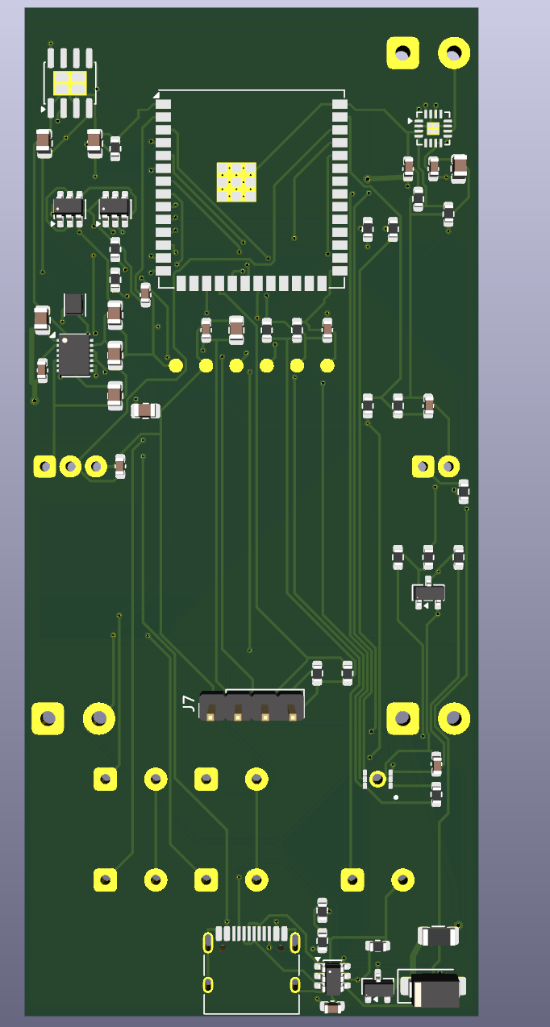
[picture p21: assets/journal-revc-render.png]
Revision C rendered PCB


As you can see, for the OLED, I put it in the center, and targetted for a commercial oled from aliexpress as they were much cheaper and jlbpcb said it was hard to solder them. I actually had another reason for this: If I had the oled directly on the PCB, it would be shallow, and the buttons would increase the entire pcb system's height, while the oled stayed at the bottom. Instead i prefered soldering the oleds with the 4 pins so they can stay at the top of the lid casing and look good. Another reason was this created space for my super slim speaker to be placed at the top. More explanation pending...

How did I route the wires?

Since this was a prototype and my main goal was to get a cost estimate, I didn't spend much time on routing. I actually was quite inexperienced and instead used this software called freerouting to help me route the hardware traces:

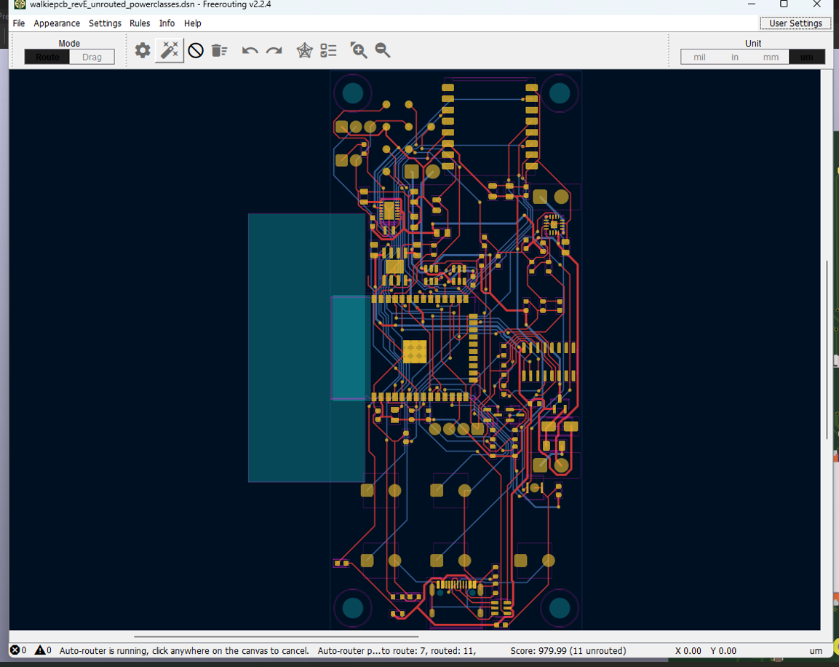
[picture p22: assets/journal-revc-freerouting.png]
Revision C in Freerouting


Here is the JLBPCB part order I used to reference my schematic into the jlbpcb parts in the PCB. Picture pending...

Ok, now time to get the jlbpcb quote:

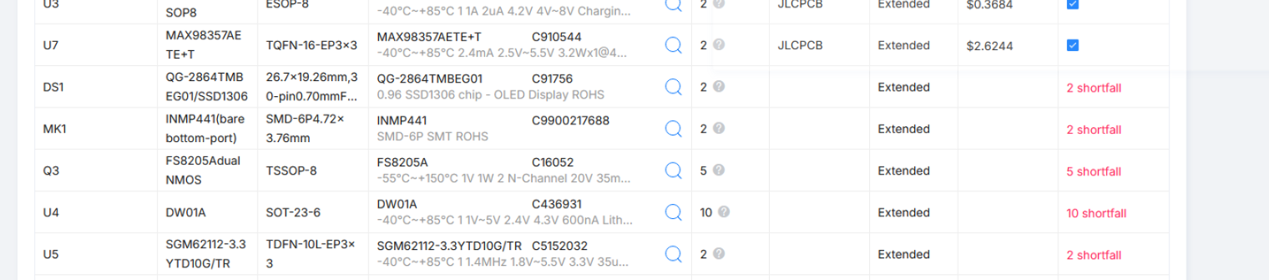
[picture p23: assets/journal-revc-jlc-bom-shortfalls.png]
Revision C JLCPCB BOM shortfalls


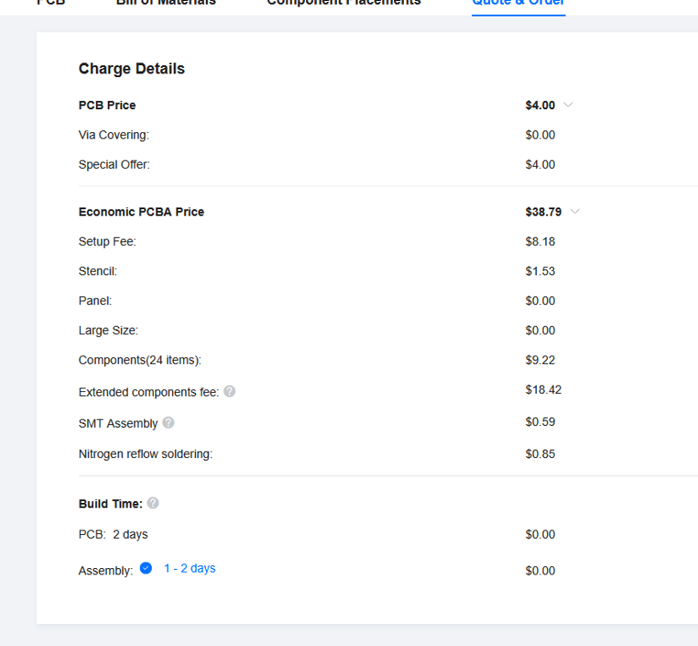
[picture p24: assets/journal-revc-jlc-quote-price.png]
Revision C JLCPCB quote price


Yeah, a lot of the components were not in stock and not extended. Meaning i'd have to pay a lot to get them in stock. I decided on revising my entire board and switching parts to in stock parts that have either extended or basic fee. The esp32 s3 itself wasn't in extended which was frustrating, they should atleast have an S3 in stock. I checked and the only esp32s were the C5, C3, and WROOM32U. I evaluated that the C versions were too slow and lacked pins so the wroom was my only option, but the problem was that now, I needed to build a UART connector which would add to the price so I decided to remove some other tooling change parts to save cost. The current quote is actually much lower than actual expected as it didn't include the esp32 and some other out of stock parts.

As you can see, I would have to switch from economic which is much cheaper to standard for the s3:

ESP32-S3 listed as Standard Only

In the new PCB, to reduce price, I was going to remove non critical components such as this battery management IC which literally added a 3 dollar tooling fee, and I couldn't find a free of charge basic version for it. It wasn't needed as i'd just find lipo batteryes with built in protection.

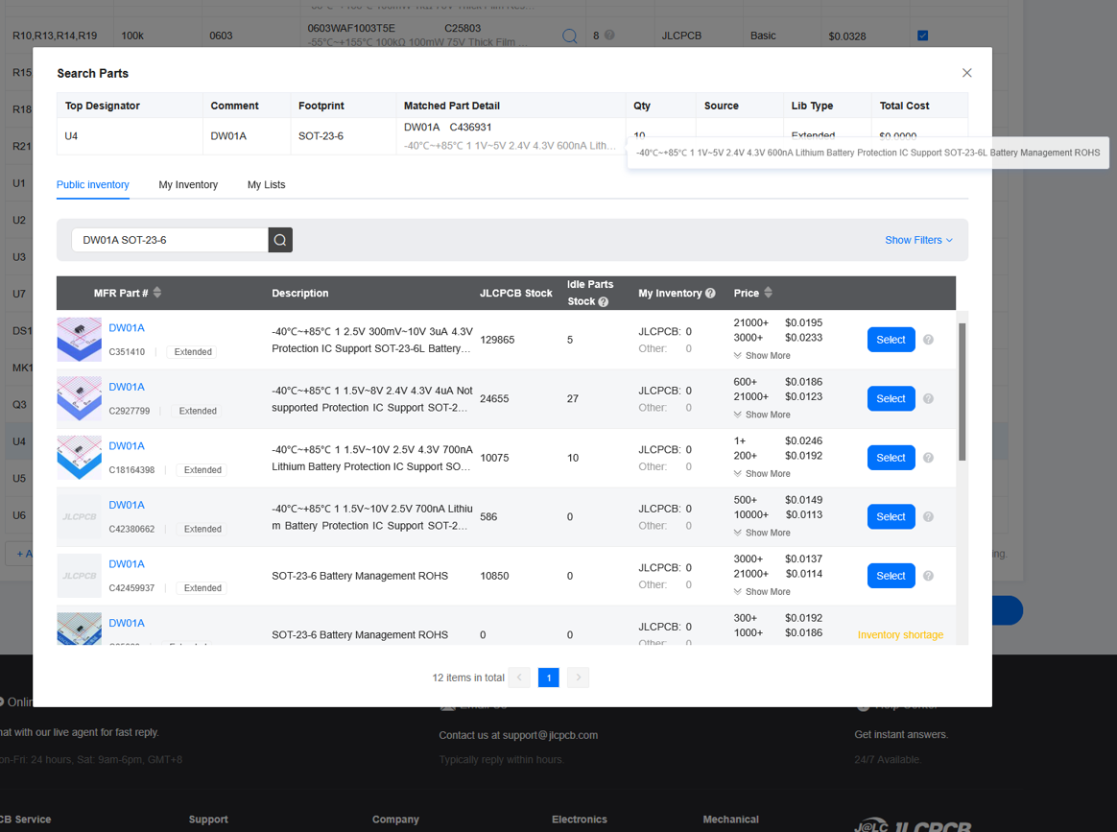
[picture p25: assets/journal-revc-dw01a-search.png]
Searching JLCPCB for a DW01A alternative


**Total time spent: 6.5 hours**

# 2026-08-26 - Revising the PCB and adding the radio.

**Date: 2026-08-26**

Today, I was going to be adding the SX1262. I added it to my schematic.

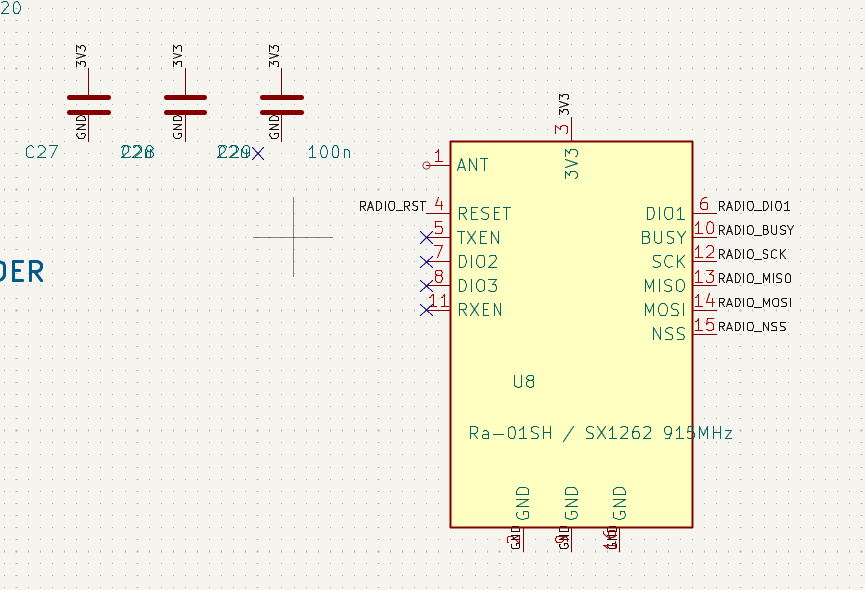
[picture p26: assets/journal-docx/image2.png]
Journal image


I also added usb uart CH340C as this didn't have native usb and i accepted that it would add to the cost but actually it would be cheaper than changing my whole design to standard:

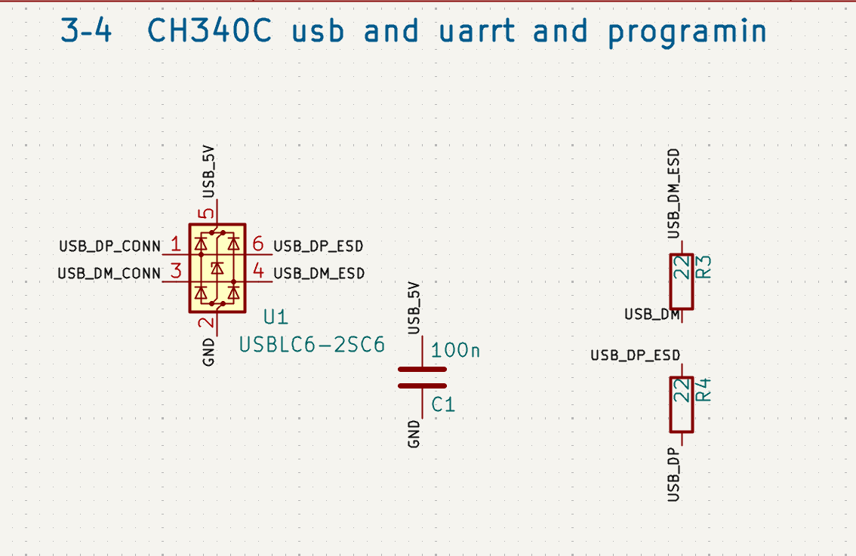
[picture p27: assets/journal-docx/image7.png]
Journal image


I switched out my S3 for a normal economic extended parts esp32 with built in antenna:

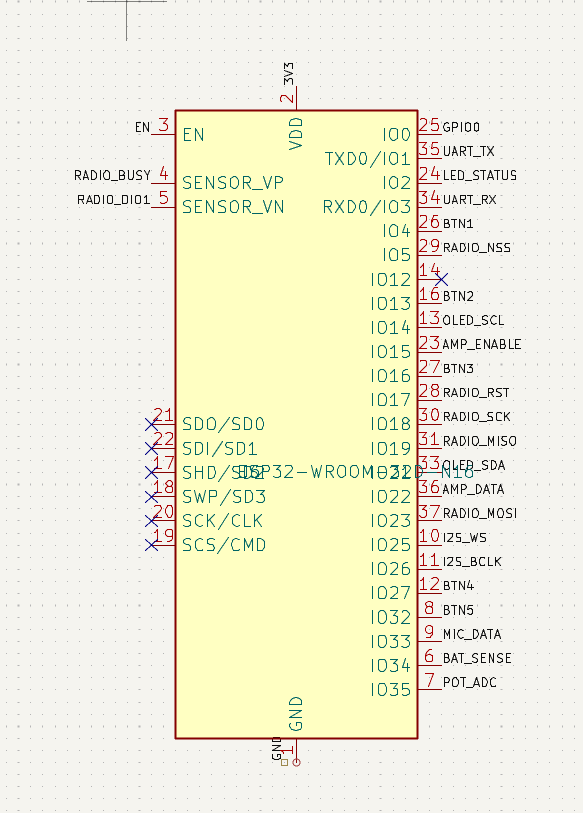
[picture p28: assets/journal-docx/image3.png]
Journal image


I had to actually change a lot of pin mappings because of this swap.

Next, I had to update my footprints. I forgot to show this in the previous journal, so a lot of it is filled in, but I filled in footprints for the new ESP32, and its new sx1262 radio, and the CH340.

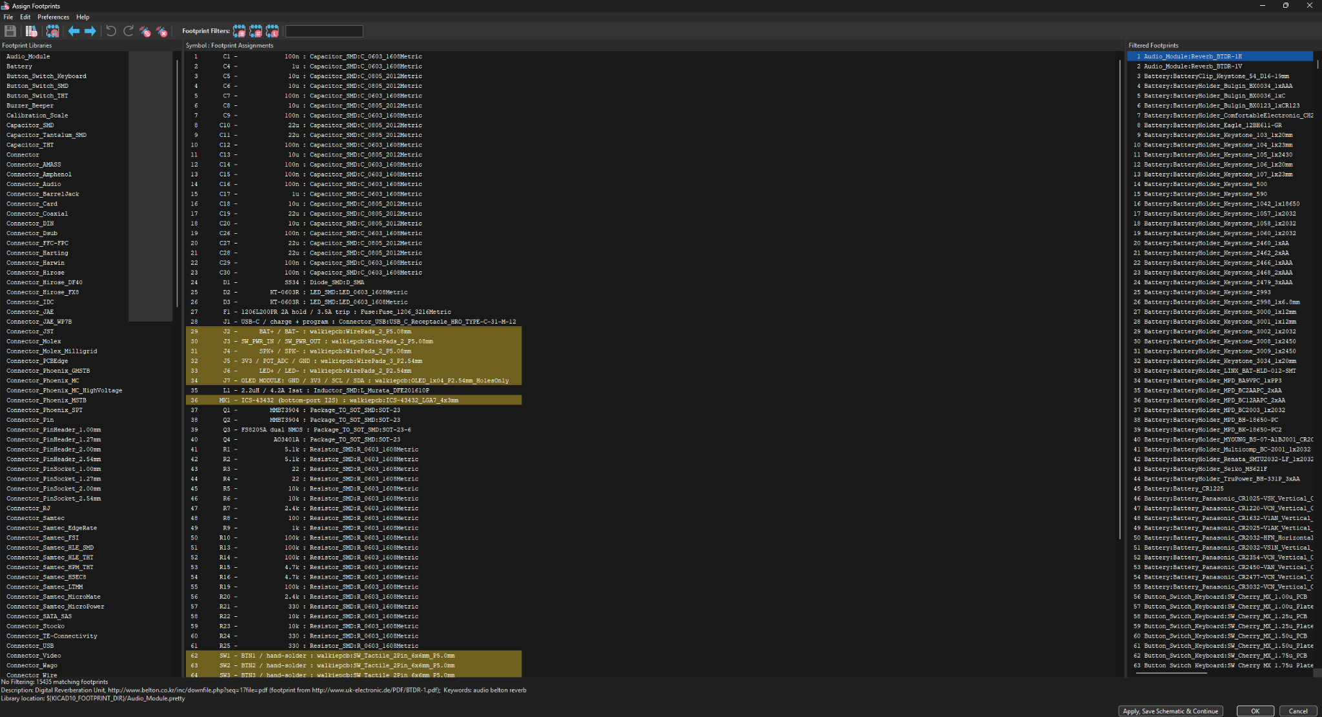
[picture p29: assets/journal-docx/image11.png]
Journal image


I made the buttons wider, to fit my casing:

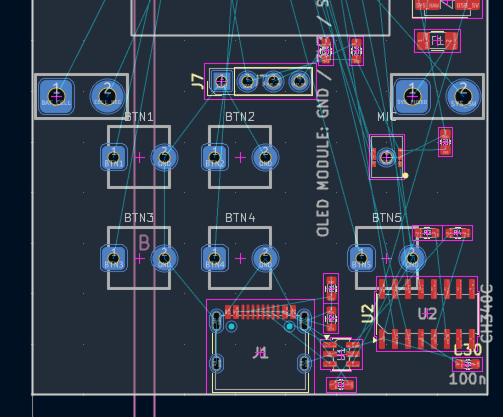
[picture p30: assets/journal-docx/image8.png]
Journal image


The top was reserved for my traces, mounting holes and radio. I needed to move the ESP32 down below.

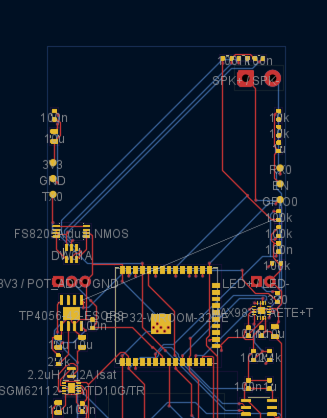
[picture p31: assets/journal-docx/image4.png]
Journal image


I now made my traces. I had to update it with the new esp32. I utilized extra pins for the radio.

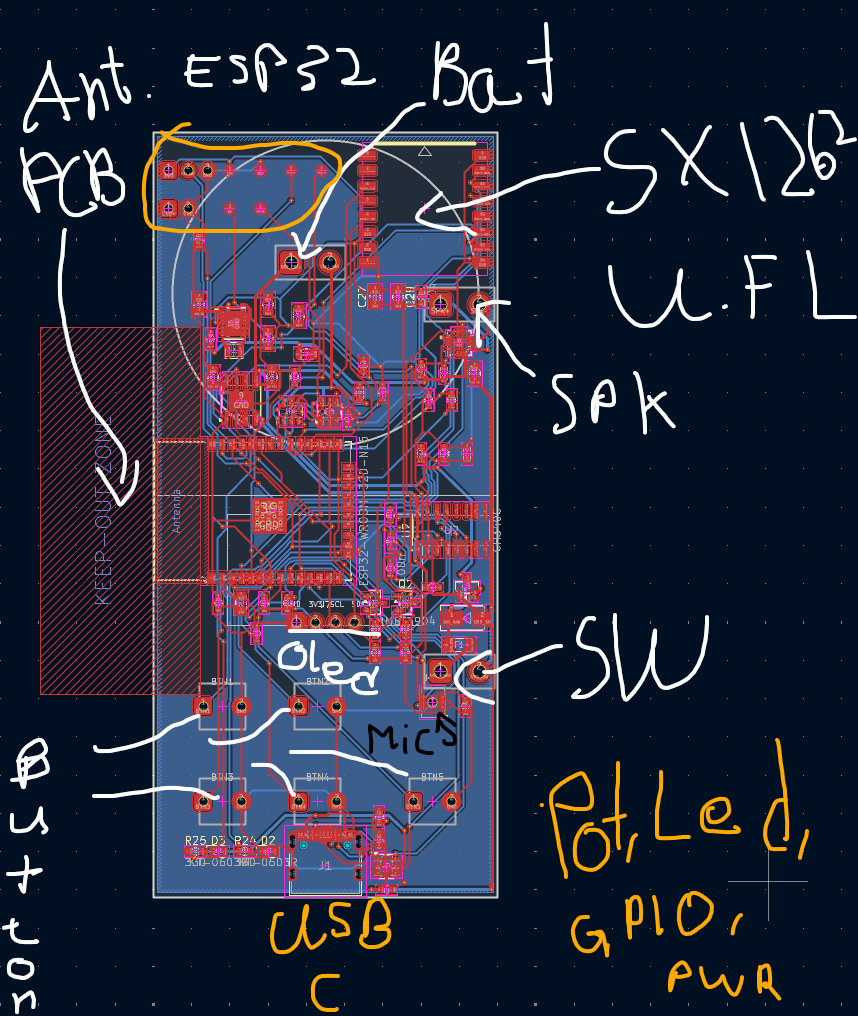
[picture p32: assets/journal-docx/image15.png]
Journal image


I only had 1 gpio available now, which I was going to be leaving out with the status LED so I could use it later on if needed for things like maybe UART. The picture has the placement of all my components.

It rendered, but some components were missing, I’ll probably fix that later. (like the radio).

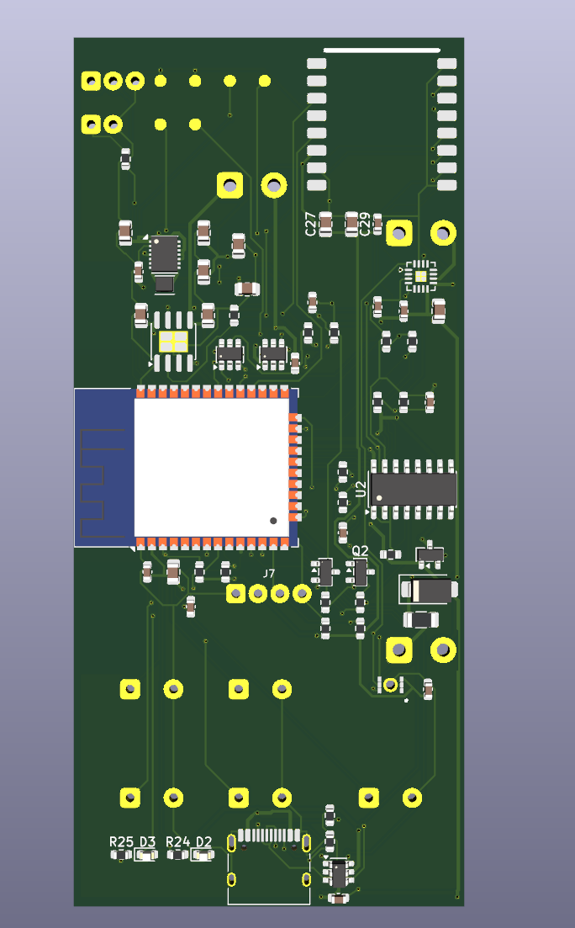
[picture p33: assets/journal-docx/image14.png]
Journal image


Time to get the quote on it.

Here is the new BOM, yay it works and accepts all the parts, because they are economic parts. So this should work.

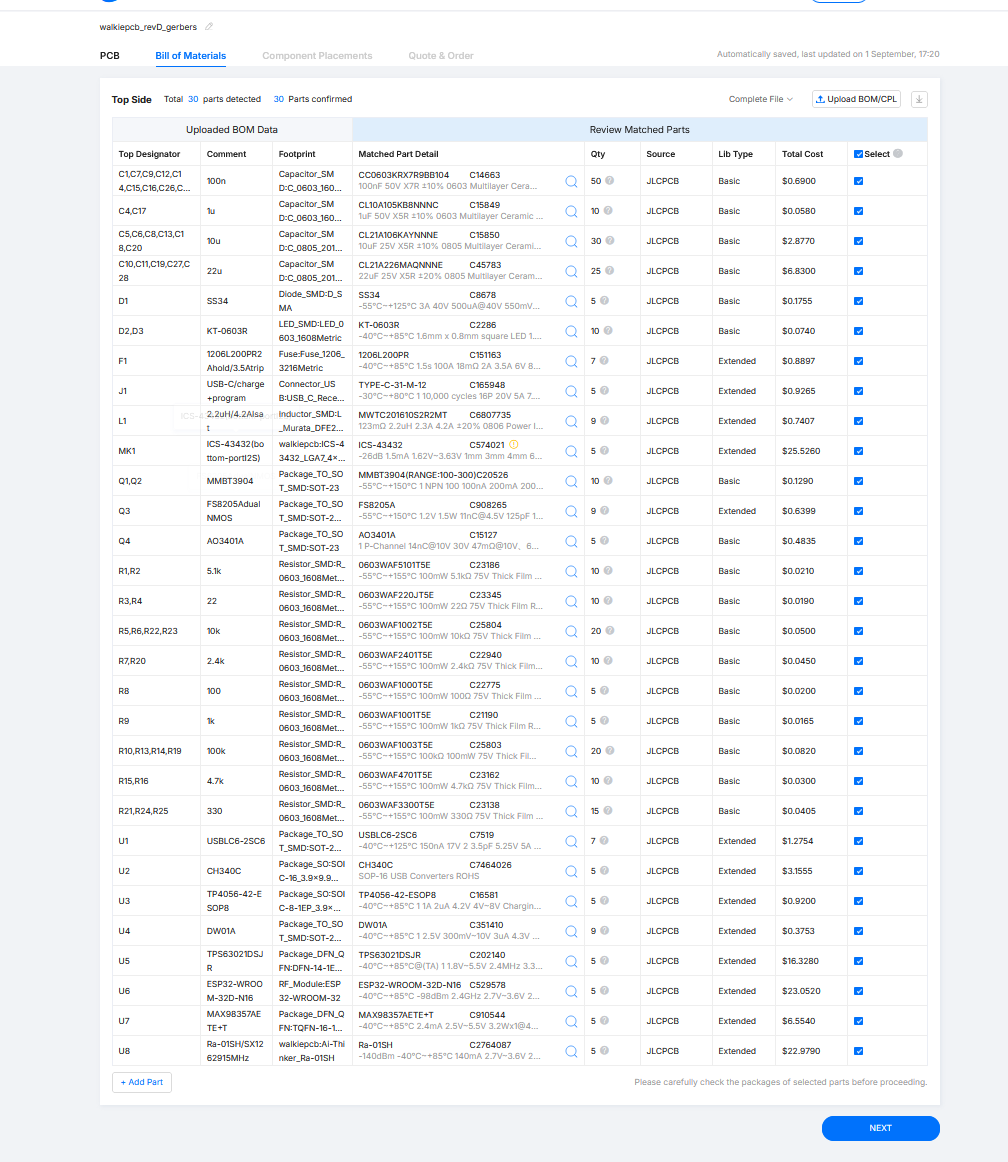
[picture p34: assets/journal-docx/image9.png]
Journal image


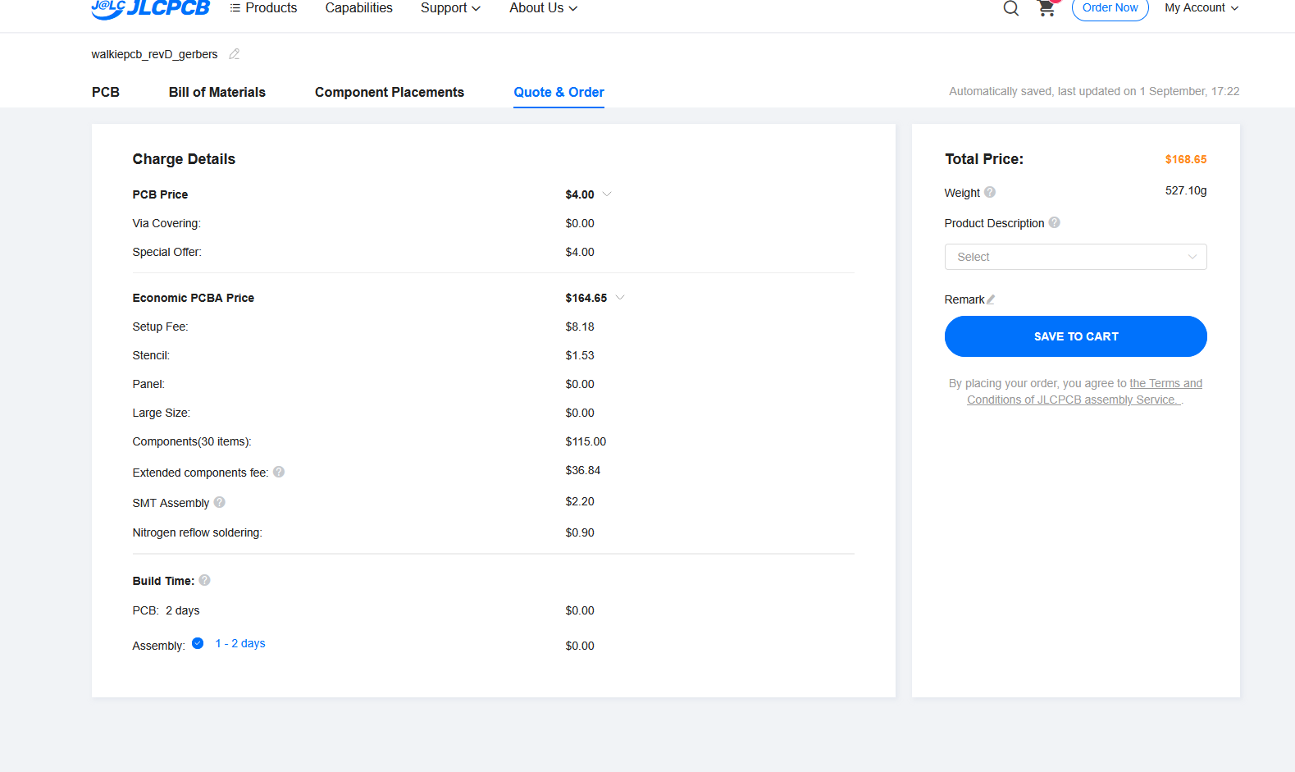
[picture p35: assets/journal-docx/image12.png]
Journal image


165 is a lot for 5 of the PCBAs, I’ll probably do two PCBAs. That's around 100 dollars.

There was a problem with the rendering though, as the placement wasn’t correct and esp32 wasn’t oriented correct, the antenna was facing downwards. I’ll fix all these issues tomorrow.

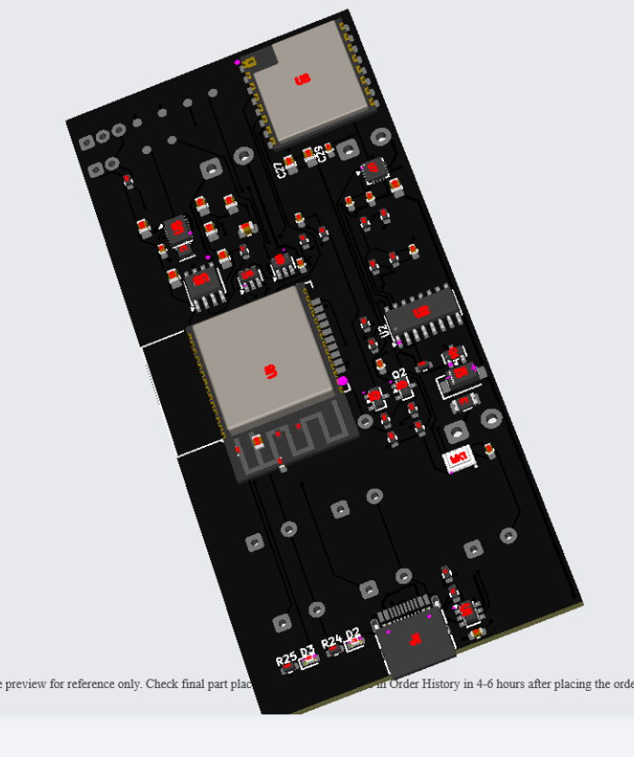
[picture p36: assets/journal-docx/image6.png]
Journal image


**Total time spent: 5.5 hours**

# 2026-08-27 - Fixing Placement, Adding Mounting Holes and Soft Power

**Date: 2026-08-27**

I needed to fix the rendering and placement issue from yesterday. The released CPL used the wrong Y-coordinate direction. I fixed that which fixed all alignment issues

The rendering was an easy fix by putting in the right footprints.

Now the radio rendered correctly in both the pcb and in the quote:

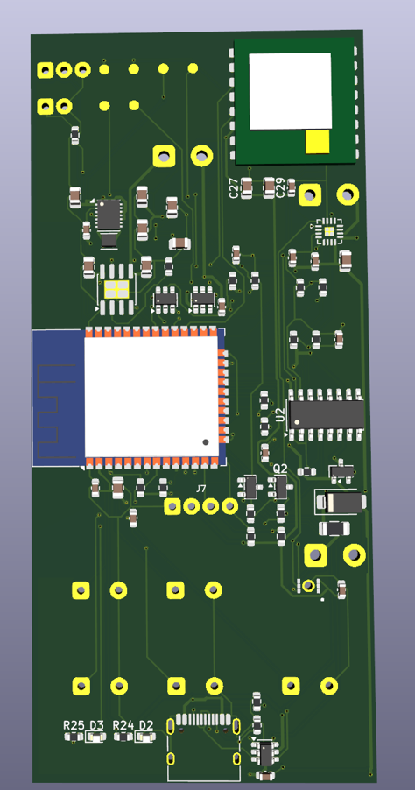
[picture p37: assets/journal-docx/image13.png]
Journal image


Now, it was the endgame. I needed to adjust my wires. But before I did that, I kind of needed to add mounting holes as I forgot to. They were essential for the 3d print. So what I did was that I moved the radio and the solder pads to fit for m3 holes:

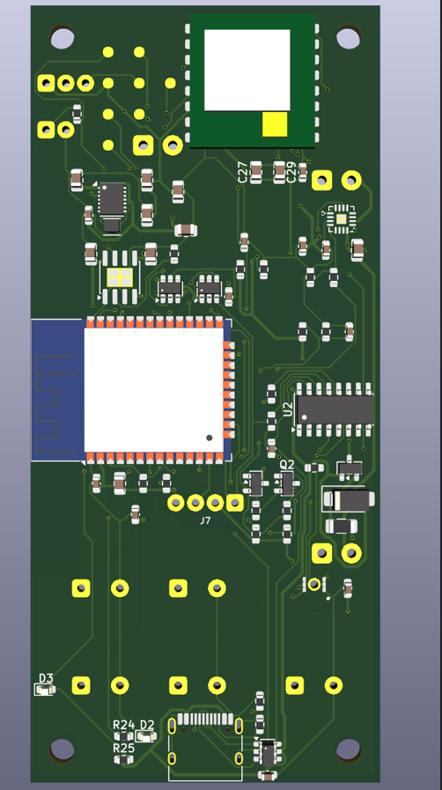
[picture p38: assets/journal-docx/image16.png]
Journal image


Also, while building the casing, I realized I didn’t want a power switch and instead kept it more simple by using the onboard push buttons as a power switch. So I was going to have to implement a soft-switch. Now here was the thing: I wanted the button to be held for a few seconds, and that gave the whole circuit power, and the esp32 then powered it on. When held again for 2 seconds, the whole thing powered off. This is the design architecture I was thinking for this, and it would be very cheap as all of the parts I was using were basic parts.

So from the battery, I had a P-mosfet.  Then the ESP32 boots. It reads the same button which is connected to its GPIO and turns on full power. The power control node has an N mosfet for the gpio from where it can turn it off when shutting down. The power consumption of this circuit was minimal and longer than the lipos normal shelf life.

Chips used:

(AO3401A P-channel chip)

MMBT3904 gate pull down with 1N4148WS diodes)

I made some fixes like inverting the OLED gpios, and adding some silkscreen text on the back:

And I made the new schematic for the soft power system:

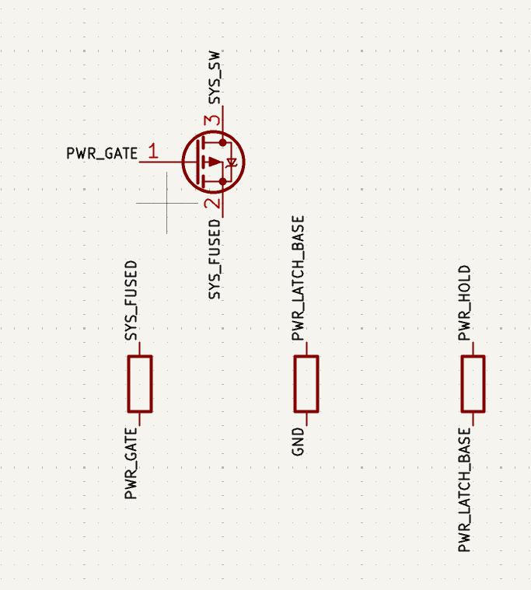
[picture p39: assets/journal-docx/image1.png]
Journal image


I also added it to the PCB:

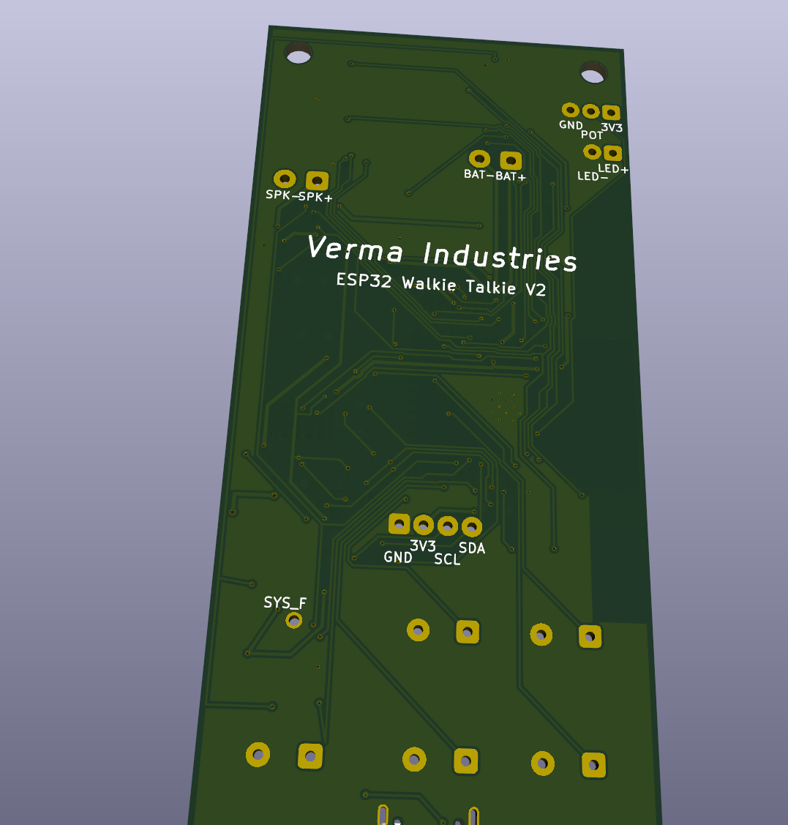
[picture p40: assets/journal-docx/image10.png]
Journal image


**Total time spent: 4 hours**

# 2026-08-28 - Designing a case

**Date: 2026-08-28**

Designing a case

I had to design a case from the ground up, because my old one was not parametric and I couldn’t copy it.

Here is me designing the new case (timelapse):

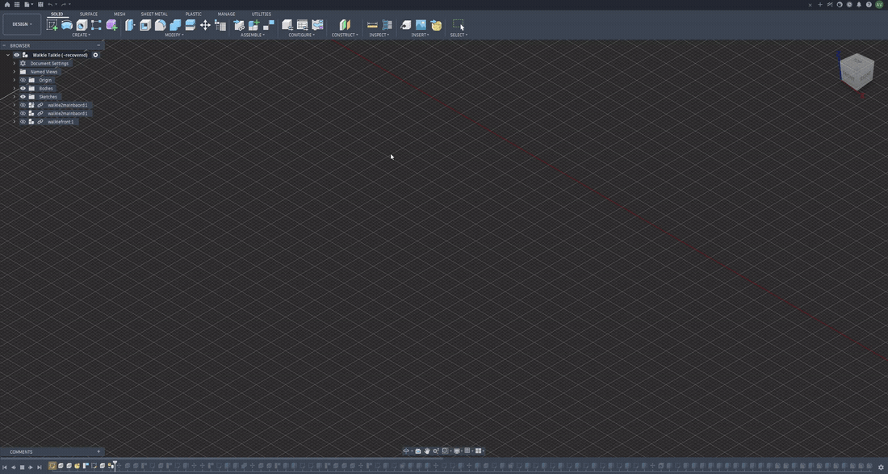
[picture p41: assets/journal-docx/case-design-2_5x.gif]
Case design timelapse at 2.5× speed


This case looked similar to the old one but was MUCH easier to assembly and much better due to the fact that the buttons were snap in and rested in place. It had 2 times as less print parts then last time. In fact, it was just the case, and two buttons. Easiest print ever. This walkie talkie was going to be super easy to build. I also had plans on making it waterproof, by using glue to seal it, and on the buttons, using a silicone sleeve or TPU which would make the thing waterproof.

It still had the 5 buttons but the PTT and LED were removed, though I kept the laser. There was a space for the POT. The laser could actually be easily replaced with an IR module instead for other stuff. This version was much easier as it used screws and not press-fit/glue.

**Total time spent: 4 hours**

# 2026-08-29 - Finalizing the PCB and Fixing Bugs

**Date: 2026-08-29**

I finalized my PCB and I wanted to look over it and confirm that it was production ready. I looked over it and I definitely found some bugs.

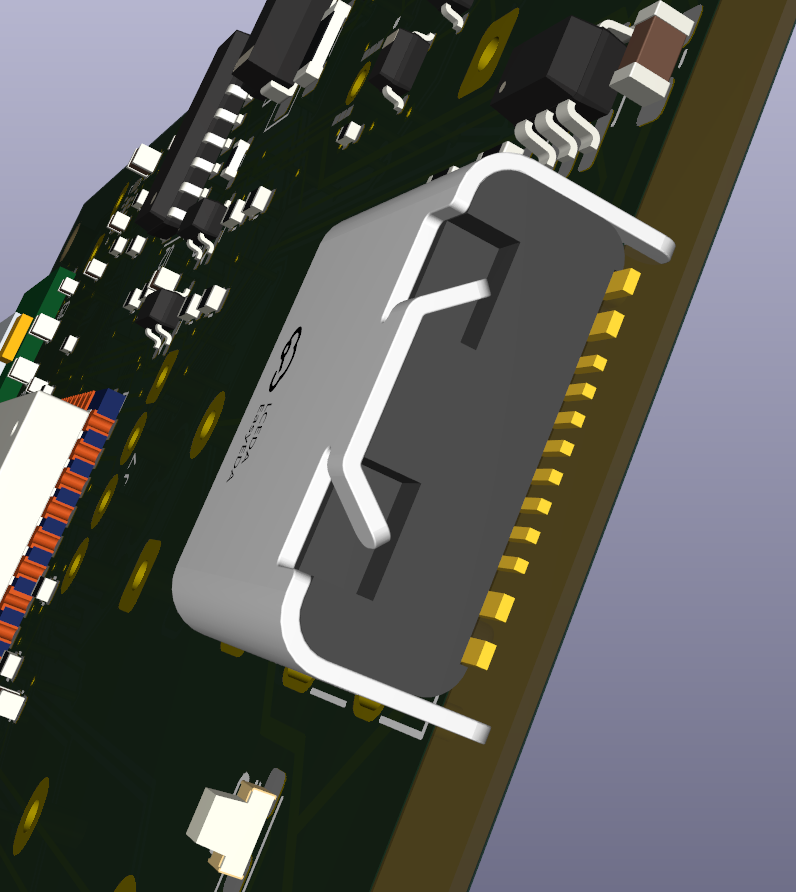
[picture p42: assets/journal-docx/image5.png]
Journal image


I had misaligned my USB c port. I also had a false resistor, and my schematic was a little different in BOM from my pcb. This was likely due to me accidentally deleting something. So I fixed them, and after a while of staring, and searching up diagrams and PINOUTS for the components in my project to make sure they weren’t missing any filtering or external support components, I finalized my PCB and it I think it is production ready. Now I need to make my github repo.

**Total time spent: 2 hours**

# 2026-08-30 - Making the github repo, documentation and and submitting for review

**Date: 2026-08-30**

I made a quick change to the cad, adding space for this laser, or IR, both can be used among walkies. They are good flipper zero likes tools.

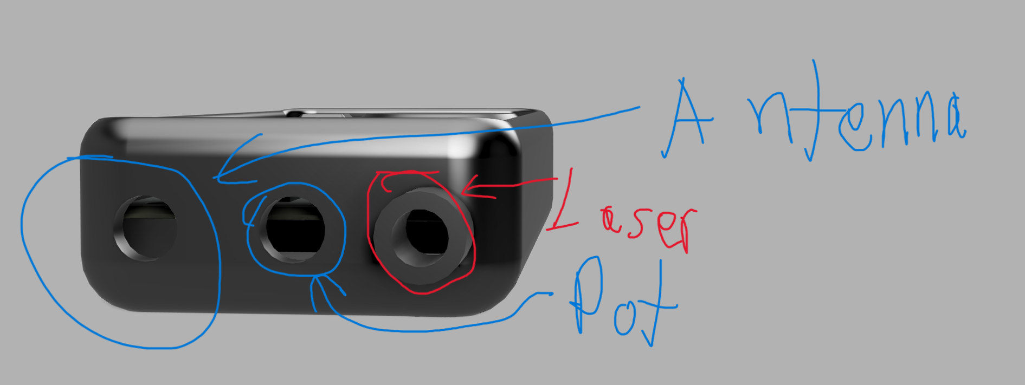
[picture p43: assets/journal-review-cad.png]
CAD with space for the laser or IR module


Now, I was working on the readme, organizing it to hack club standards and including my CAD, schematics, and firmware

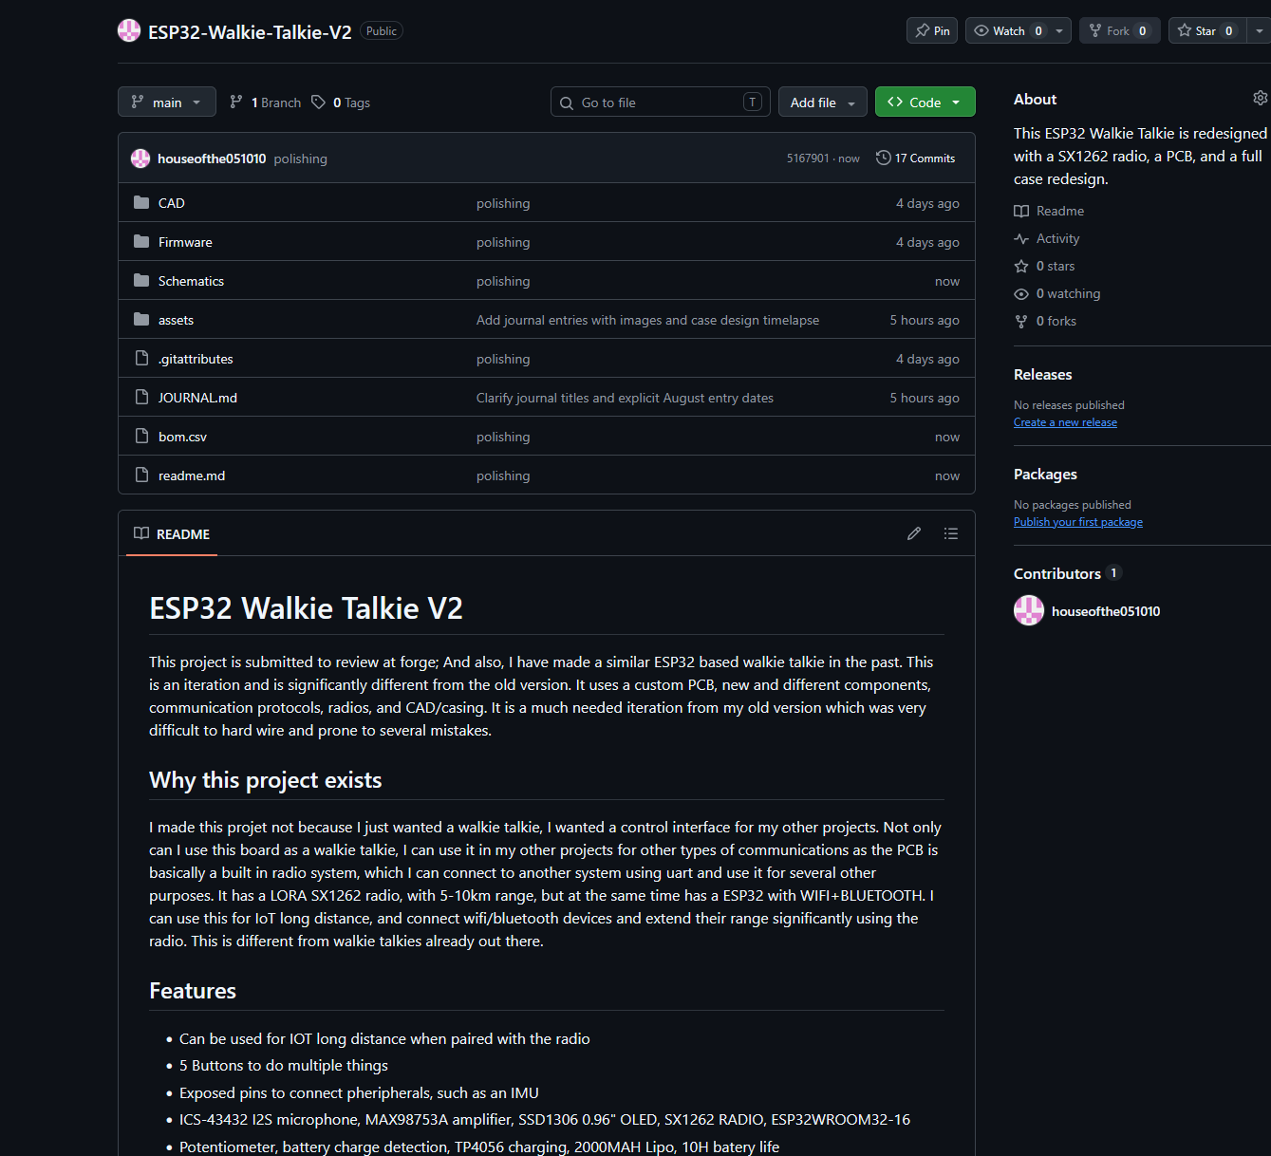
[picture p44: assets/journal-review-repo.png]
GitHub repository and README


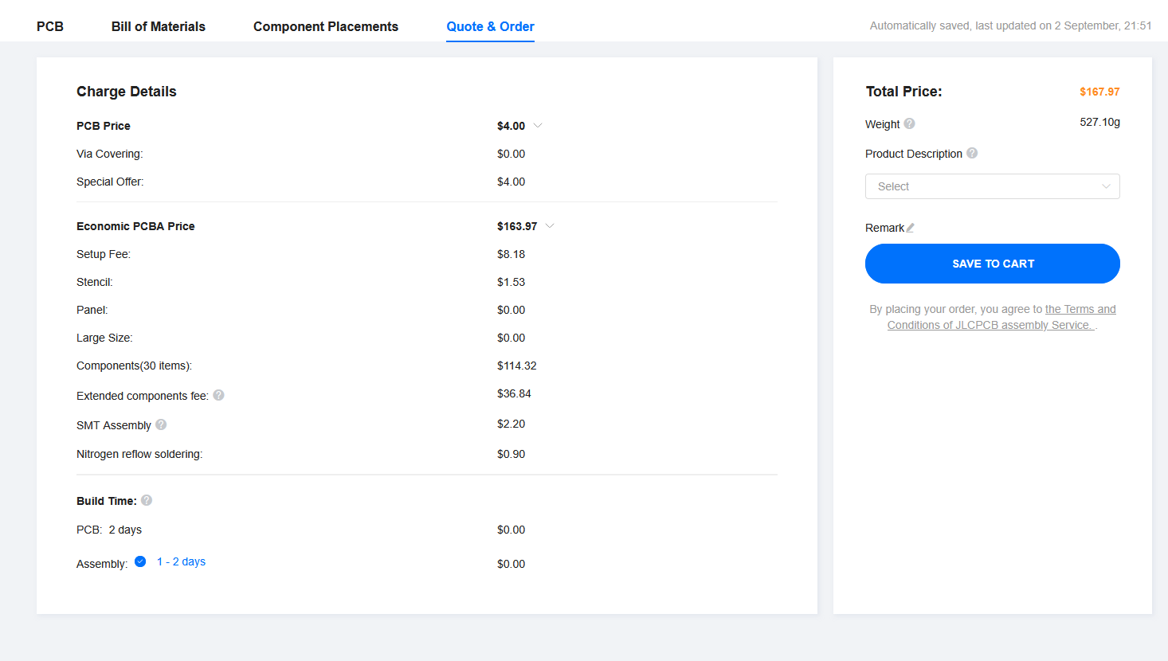
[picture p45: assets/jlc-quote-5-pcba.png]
Final quote for five PCBAs


I also quote the final quote, which was 163 for 5 PCBAs. The price went down to around 99 dollars when I switched to two PCBAs, which was much better:

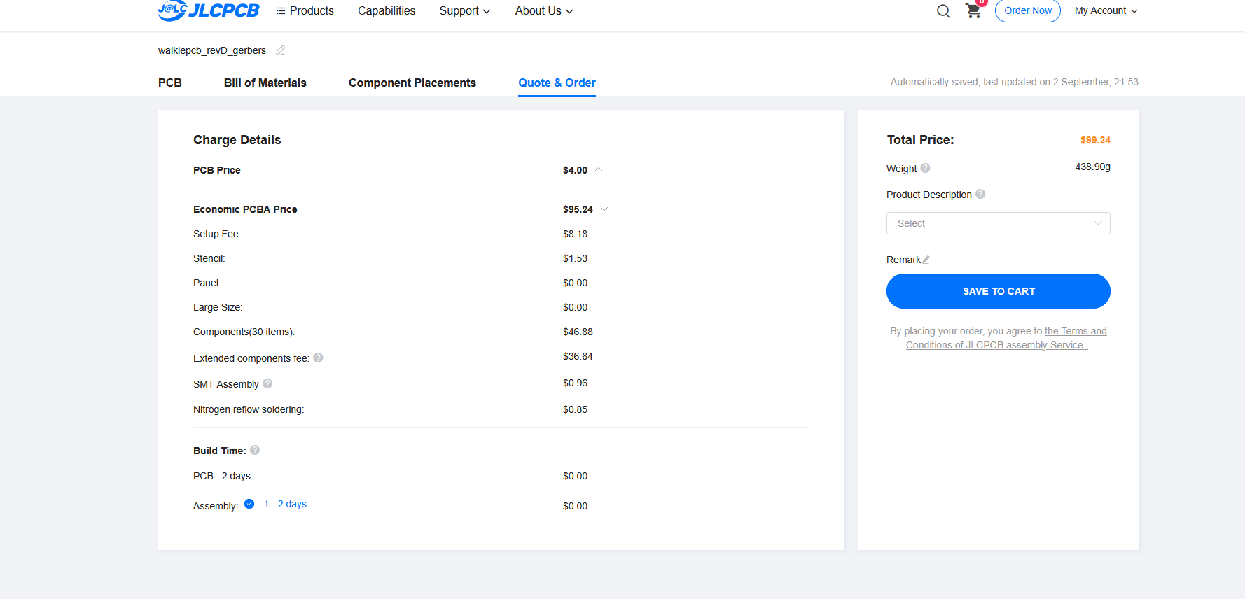
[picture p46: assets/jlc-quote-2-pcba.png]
Final quote for two PCBAs


I updated and made my BOM

I will submit for review now

**Total time spent: 2 hours**

# 2026-09-05 - Adding firmware

**Date: 2026-09-05**

**Time: 11:41 AM**

I needed to add basic firmware as the review required it. I used micropython in thonny as it was super easy to make firmware, none of the C compiling like I do with esp-idf. I built short code that sends a signal to the other walkie talkie and the other walkie talkie responds.

(thonny cant be tracked by hackatime)

Basic MicroPython radio firmware in Thonny

**Total time spent: 30 minutes**

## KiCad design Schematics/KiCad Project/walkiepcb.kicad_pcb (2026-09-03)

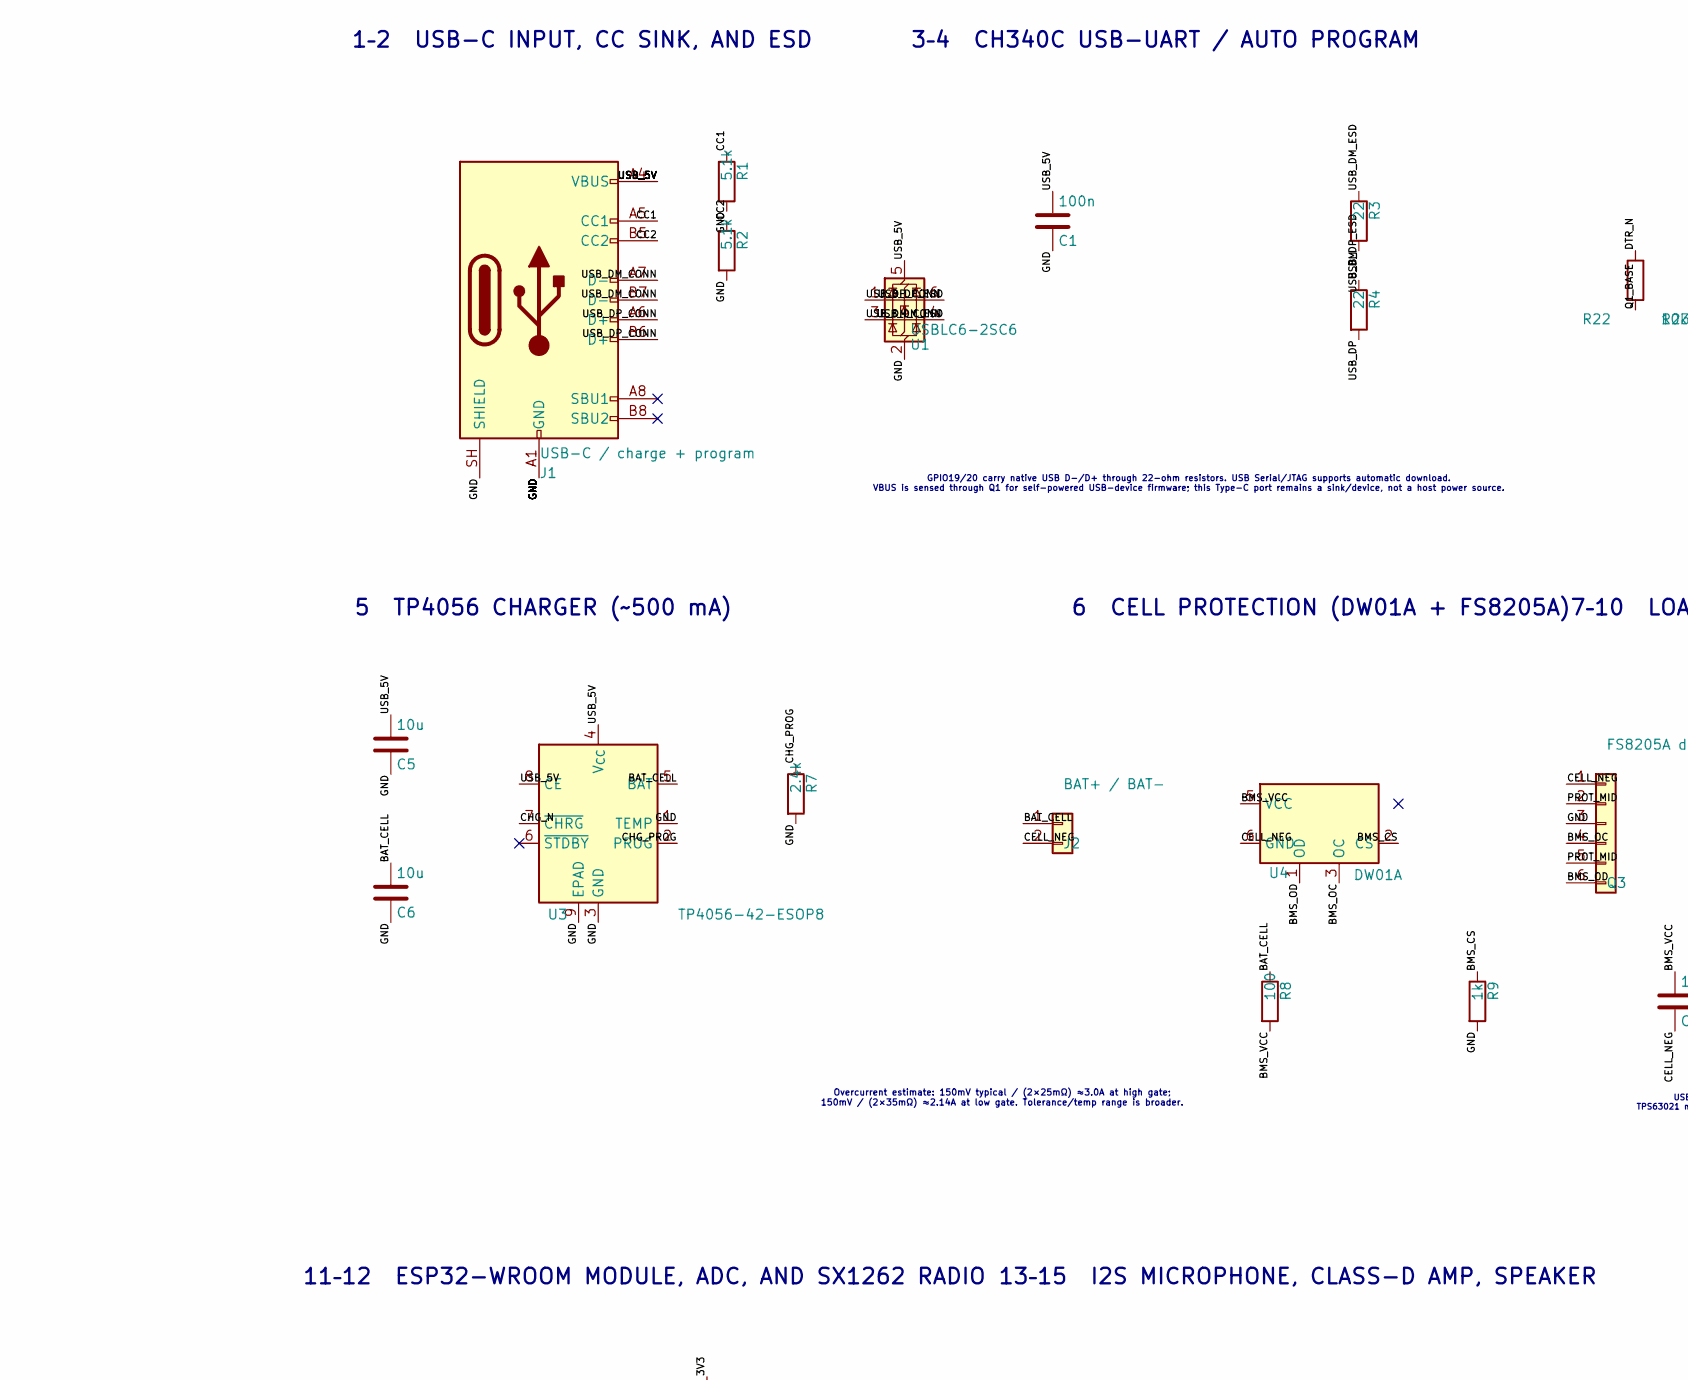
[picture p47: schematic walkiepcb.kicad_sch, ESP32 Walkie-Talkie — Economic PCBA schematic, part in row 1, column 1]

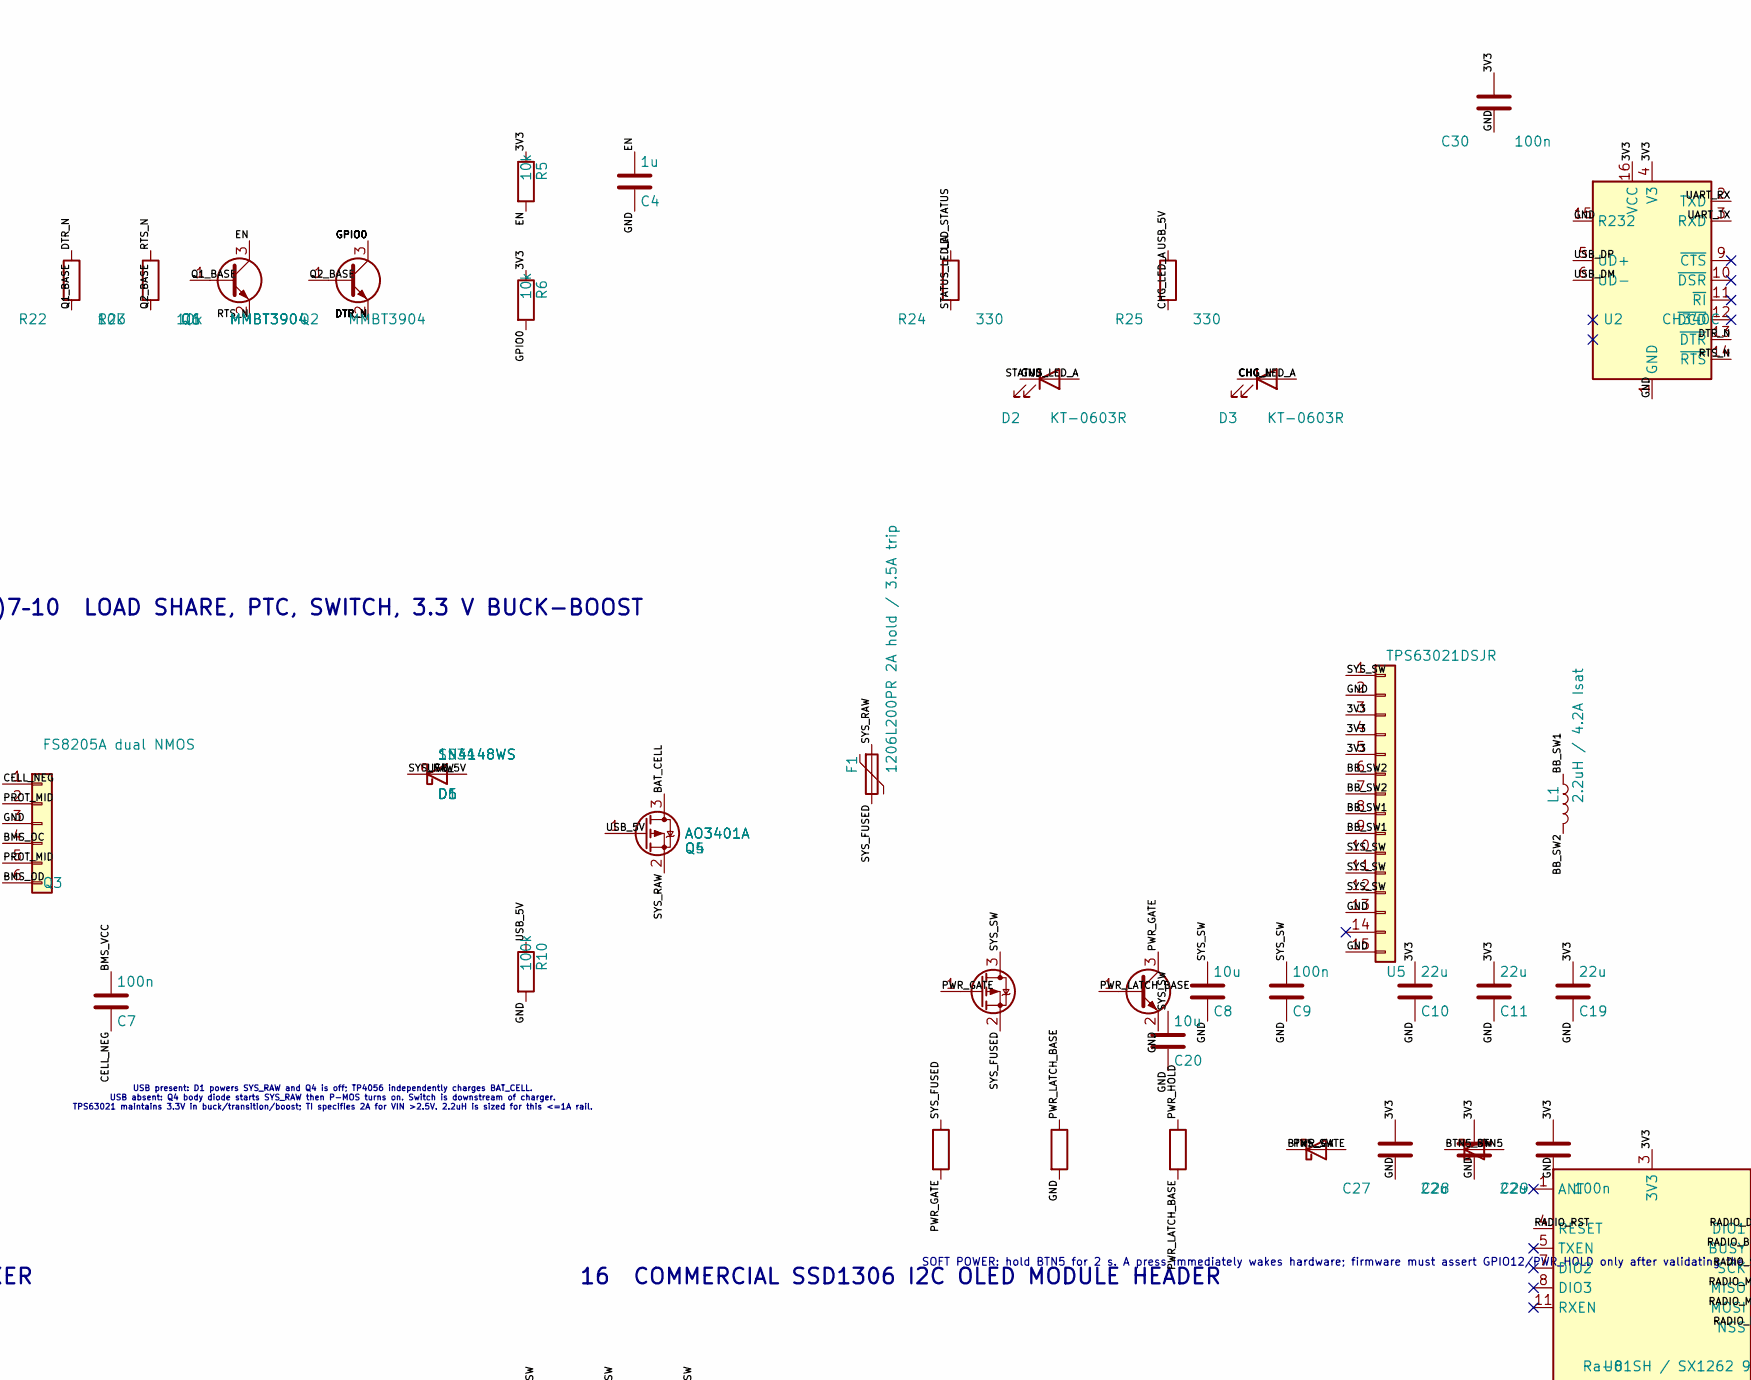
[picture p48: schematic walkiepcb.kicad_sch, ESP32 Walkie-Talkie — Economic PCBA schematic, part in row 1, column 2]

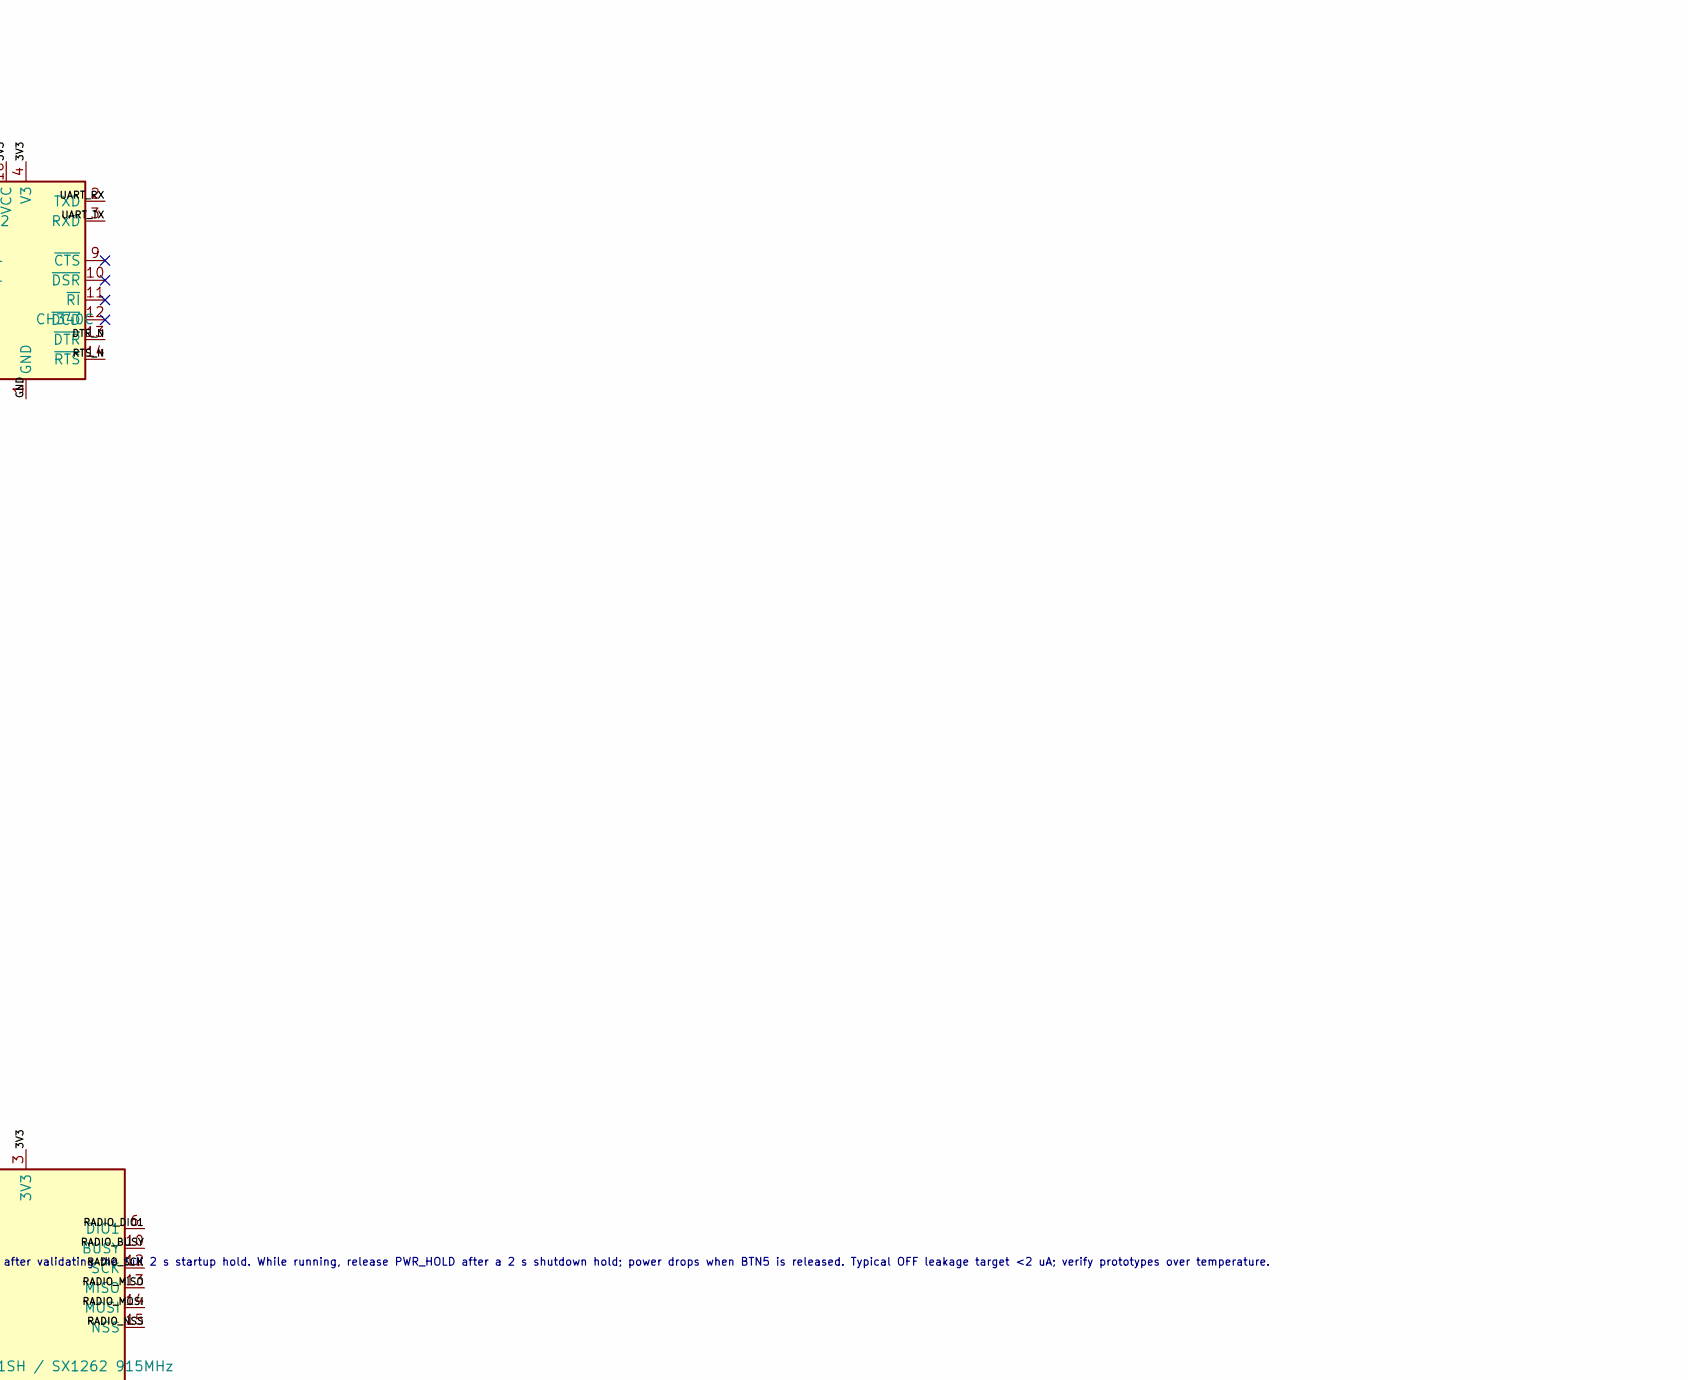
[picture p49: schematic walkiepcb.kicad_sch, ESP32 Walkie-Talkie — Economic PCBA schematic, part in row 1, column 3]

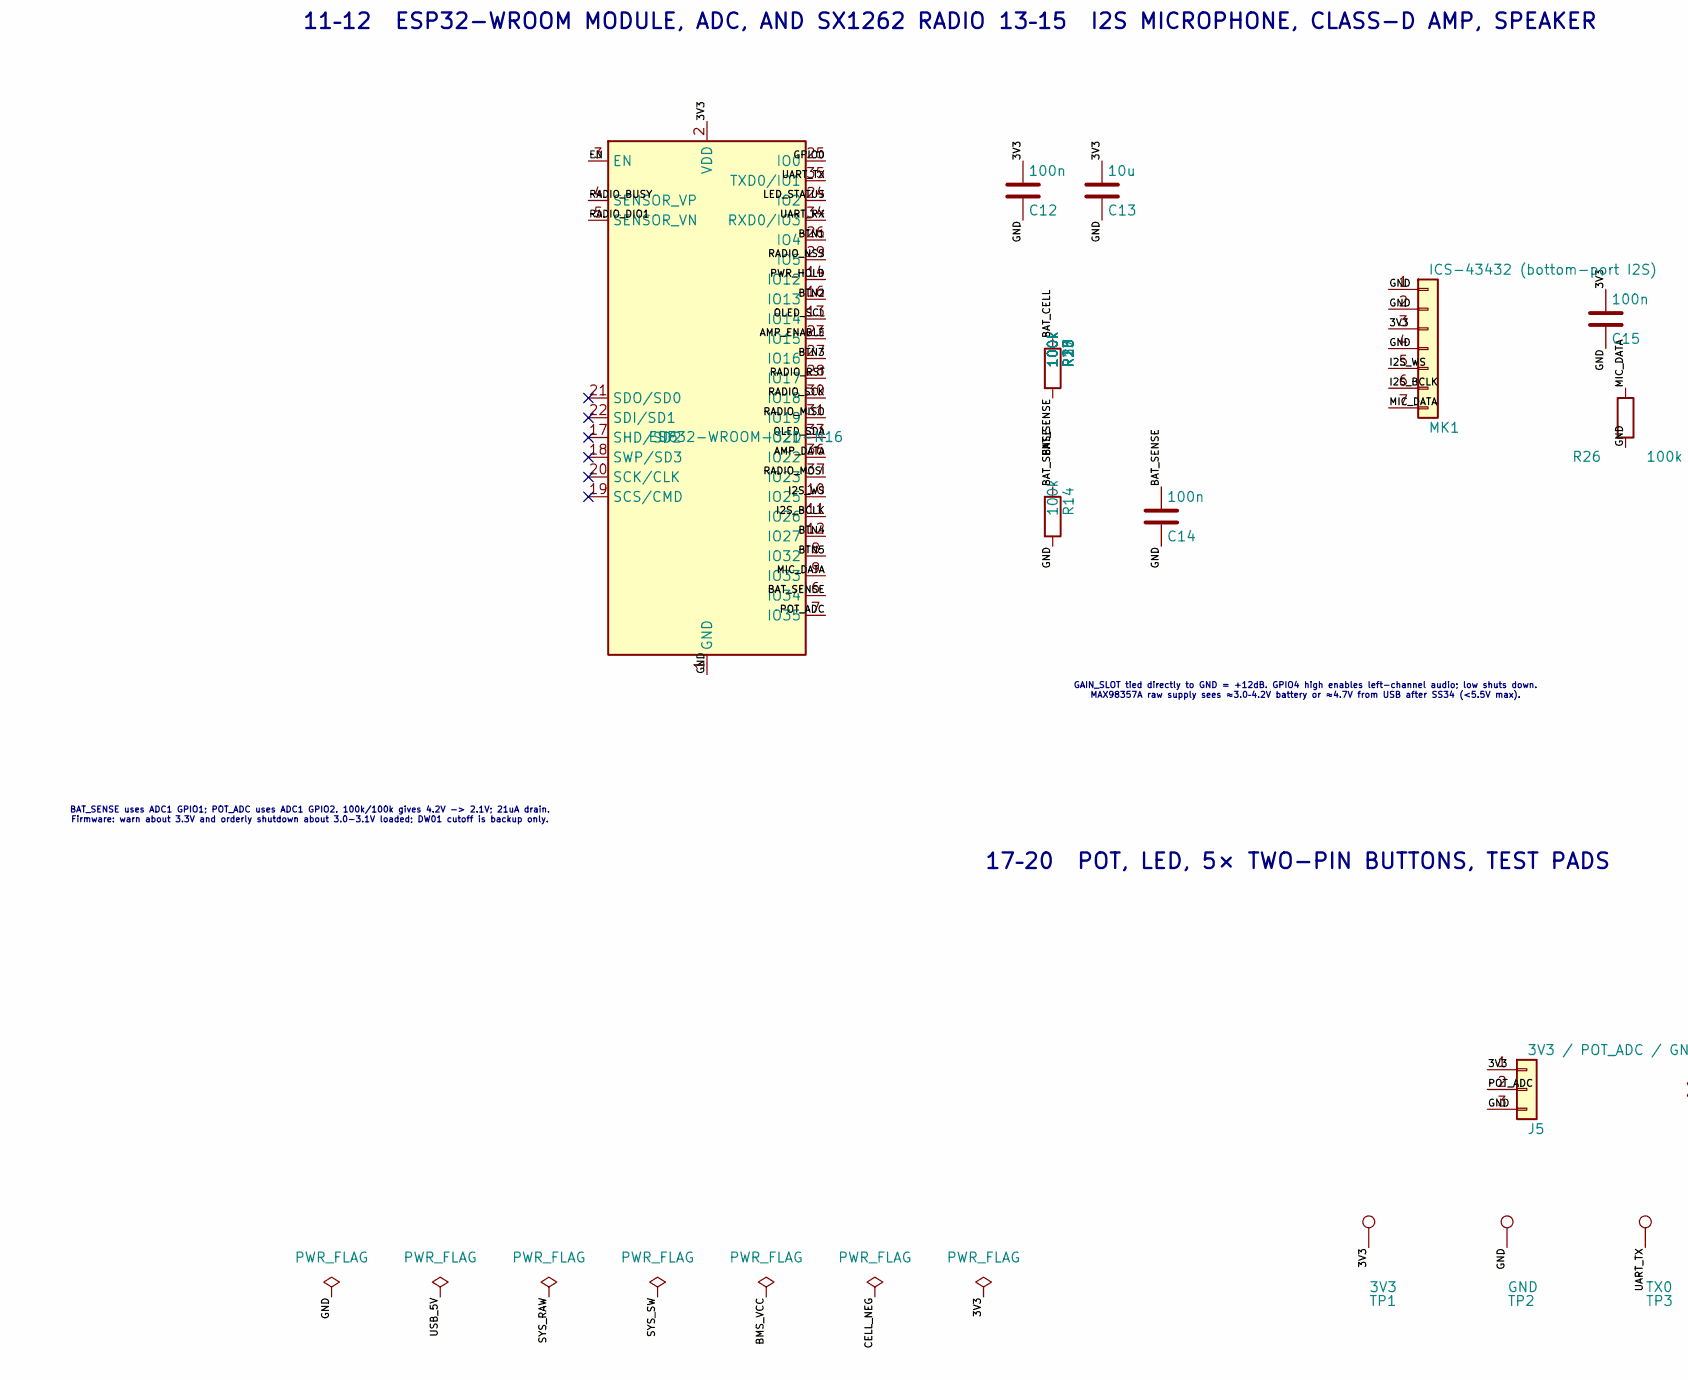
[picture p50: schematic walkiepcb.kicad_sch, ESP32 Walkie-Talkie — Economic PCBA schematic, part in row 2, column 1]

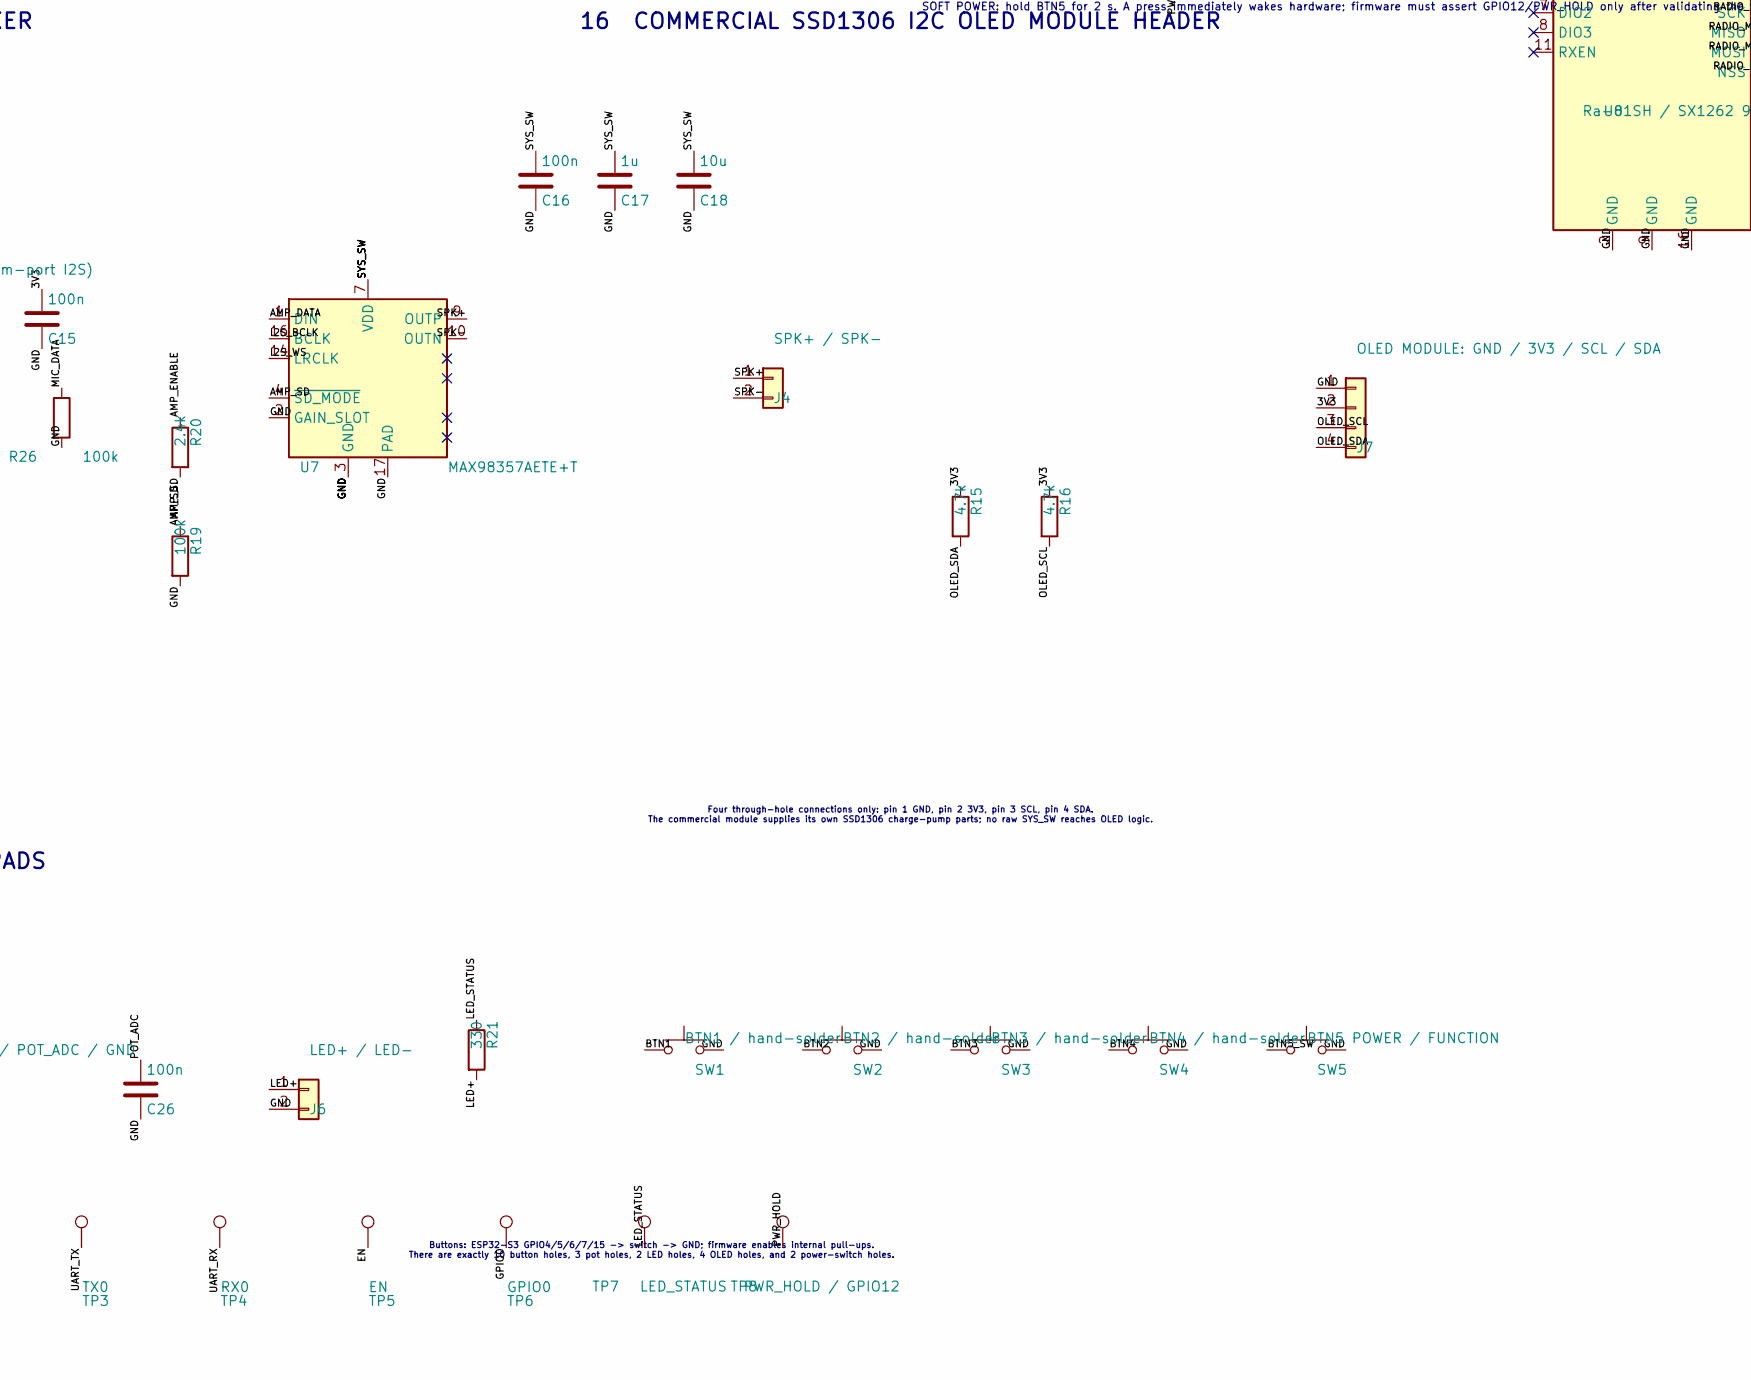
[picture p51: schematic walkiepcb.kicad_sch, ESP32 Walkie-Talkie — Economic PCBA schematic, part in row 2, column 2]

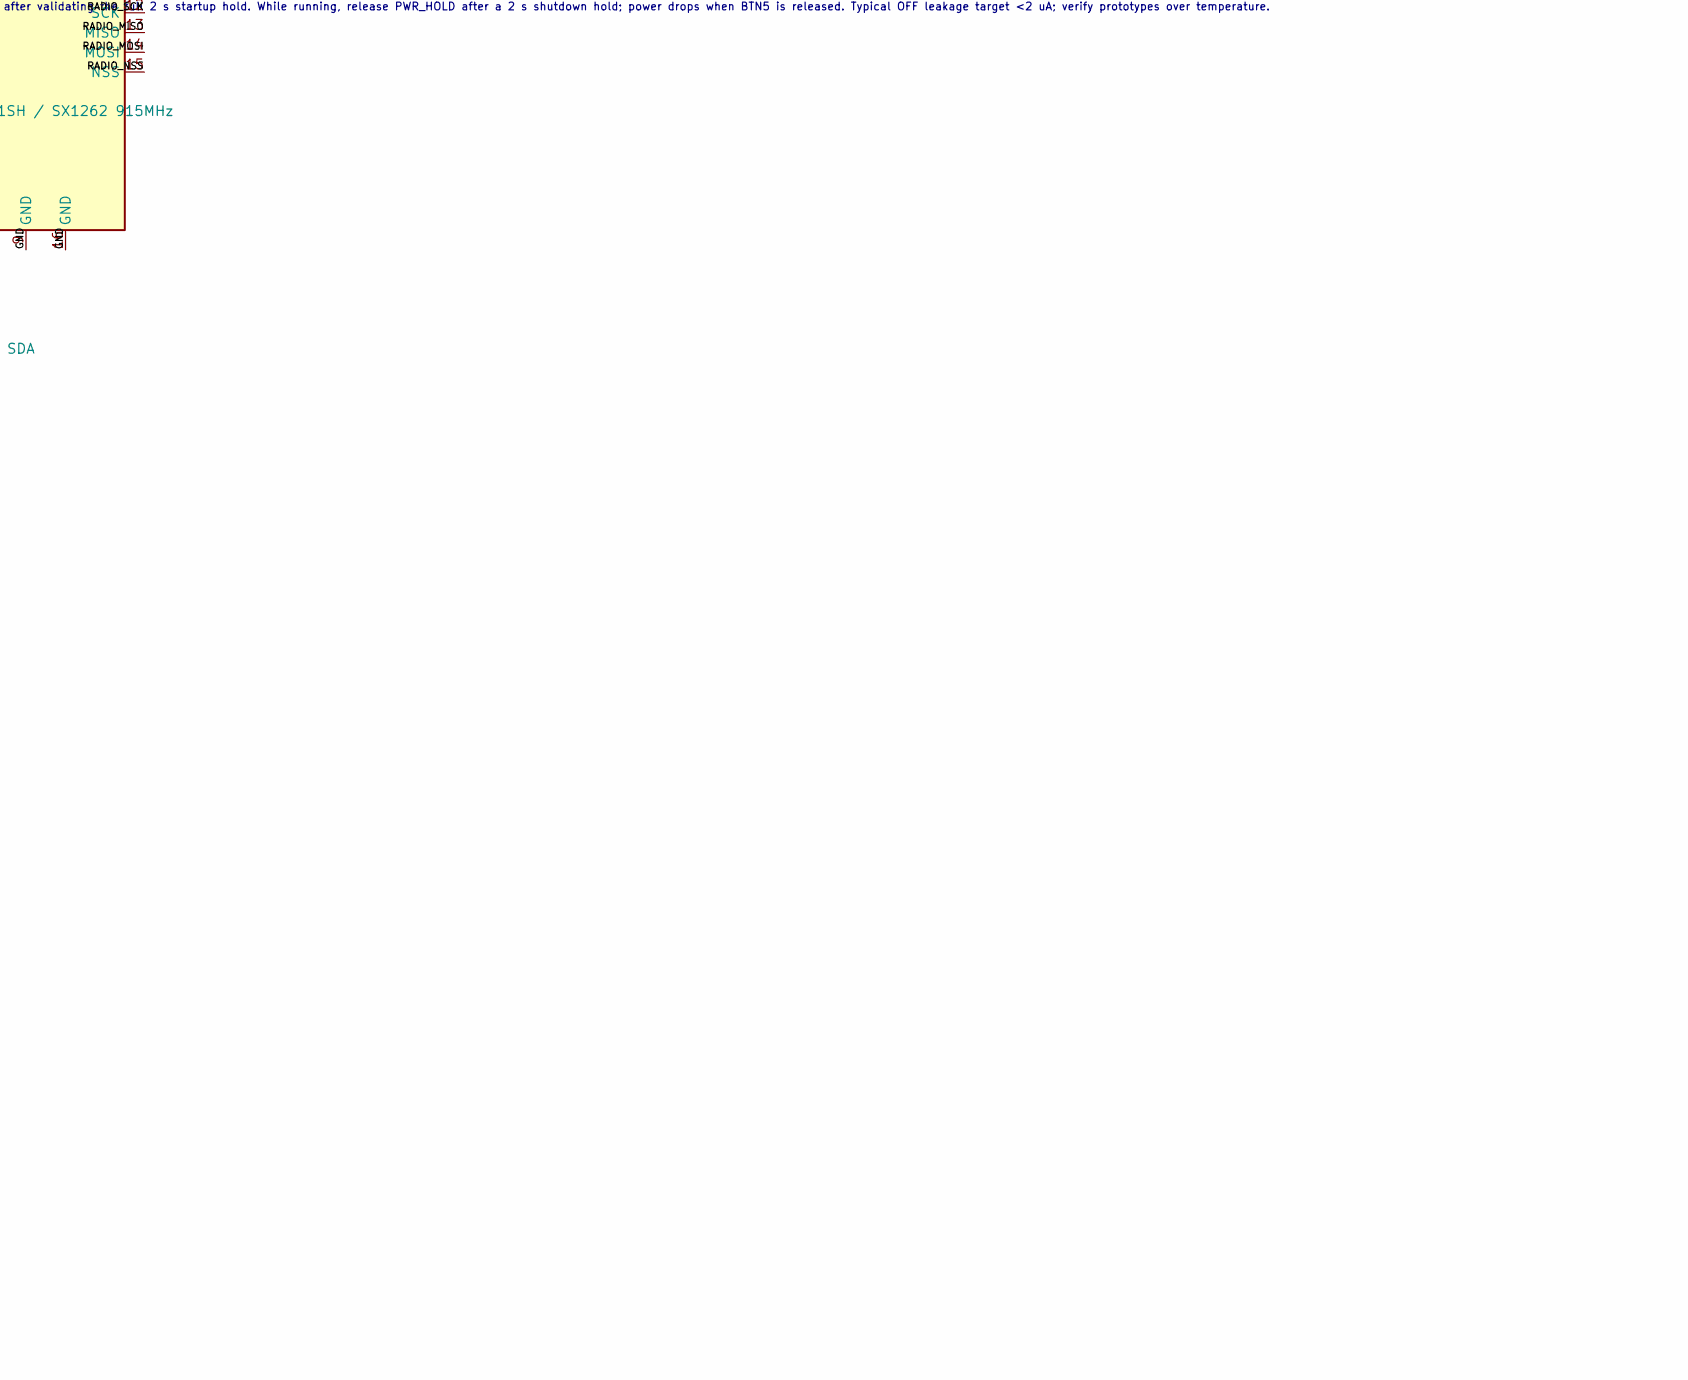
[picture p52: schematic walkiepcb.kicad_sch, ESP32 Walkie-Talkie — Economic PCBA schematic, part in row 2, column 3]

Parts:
C1, C7, C9, C12, C14, C15, C16, C26, C29, C30: 100n; C_0603_1608Metric; MPN CC0603KRX7R9BB104; JLC/LCSC C14663
C4, C17: 1u; C_0603_1608Metric; MPN CL10A105KB8NNNC; JLC/LCSC C15849
C5, C6, C8, C13, C18, C20: 10u; C_0805_2012Metric; MPN CL21A106KAYNNNE; JLC/LCSC C15850
C10, C11, C19, C27, C28: 22u; C_0805_2012Metric; MPN CL21A226MAQNNNE; JLC/LCSC C45783
D1: SS34; D_SMA; MPN SS34; JLC/LCSC C8678
D2, D3: KT-0603R; LED_0603_1608Metric; MPN KT-0603R; JLC/LCSC C2286
D5, D6: 1N4148WS; D_SOD-323; MPN 1N4148WS; JLC/LCSC C2128
F1: 1206L200PR 2A hold / 3.5A trip; Fuse_1206_3216Metric; MPN 1206L200PR; JLC/LCSC C151163
J1: USB-C / charge + program; USB_C_Receptacle_HRO_TYPE-C-31-M-12; MPN TYPE-C-31-M-12; JLC/LCSC C165948
J2: BAT+ / BAT-; WirePads_2_P5.08mm; MPN 2 solder pads; JLC Classification DNP
J4: SPK+ / SPK-; WirePads_2_P5.08mm; MPN 2 solder pads; JLC Classification DNP
J5: 3V3 / POT_ADC / GND; WirePads_3_P2.54mm; MPN 3 solder pads; JLC Classification DNP
J6: LED+ / LED-; WirePads_2_P2.54mm; MPN 2 solder pads; JLC Classification DNP
J7: OLED MODULE: GND / 3V3 / SCL / SDA; OLED_1x04_P2.54mm_HolesOnly; MPN 2.54mm 1x4 header; JLC Classification DNP
L1: 2.2uH / 4.2A Isat; L_Murata_DFE201610P; MPN MWTC201610S2R2MT; JLC/LCSC C6807735
MK1: ICS-43432 (bottom-port I2S); ICS-43432_LGA7_4x3mm; MPN ICS-43432; JLC/LCSC C574021
Q1, Q2, Q6: MMBT3904; SOT-23; MPN MMBT3904; JLC/LCSC C20526
Q3: FS8205A dual NMOS; SOT-23-6; MPN FS8205A; JLC/LCSC C908265
Q4, Q5: AO3401A; SOT-23; MPN AO3401A; JLC/LCSC C15127
R1, R2: 5.1k; R_0603_1608Metric; MPN 0603WAF5101T5E; JLC/LCSC C23186
R3, R4: 22; R_0603_1608Metric; MPN 0603WAF220JT5E; JLC/LCSC C23345
R5, R6, R22, R23: 10k; R_0603_1608Metric; MPN 0603WAF1002T5E; JLC/LCSC C25804
R7, R20: 2.4k; R_0603_1608Metric; MPN 0603WAF2401T5E; JLC/LCSC C22940
R8: 100; R_0603_1608Metric; MPN 0603WAF1000T5E; JLC/LCSC C22775
R9: 1k; R_0603_1608Metric; MPN 0603WAF1001T5E; JLC/LCSC C21190
R10, R13, R14, R19: 100k; R_0603_1608Metric; MPN 0603WAF1003T5E; JLC/LCSC C25803
R15, R16: 4.7k; R_0603_1608Metric; MPN 0603WAF4701T5E; JLC/LCSC C23162
R21, R24, R25: 330; R_0603_1608Metric; MPN 0603WAF3300T5E; JLC/LCSC C23138
R26, R27, R28, R30: 100k; R_0402_1005Metric; MPN 0402WGF1003TCE; JLC/LCSC C25741
SW1: BTN1 / hand-solder; SW_Tactile_2Pin_6x6mm_P5.0mm; MPN TL1100F100QG; JLC Classification DNP
SW2: BTN2 / hand-solder; SW_Tactile_2Pin_6x6mm_P5.0mm; MPN TL1100F100QG; JLC Classification DNP
SW3: BTN3 / hand-solder; SW_Tactile_2Pin_6x6mm_P5.0mm; MPN TL1100F100QG; JLC Classification DNP
SW4: BTN4 / hand-solder; SW_Tactile_2Pin_6x6mm_P5.0mm; MPN TL1100F100QG; JLC Classification DNP
SW5: BTN5 POWER / FUNCTION; SW_Tactile_2Pin_6x6mm_P5.0mm; MPN TL1100F100QG; JLC Classification DNP
TP1: 3V3; TestPad_1.0mm; MPN SMD test pad; JLC Classification PCB
TP2: GND; TestPad_1.0mm; MPN SMD test pad; JLC Classification PCB
TP3: TX0; TestPad_1.0mm; MPN SMD test pad; JLC Classification PCB
TP4: RX0; TestPad_1.0mm; MPN SMD test pad; JLC Classification PCB
TP5: EN; TestPad_1.0mm; MPN SMD test pad; JLC Classification PCB
TP6: GPIO0; TestPad_1.0mm; MPN SMD test pad; JLC Classification PCB
TP7: LED_STATUS; TestPad_1.0mm; MPN SMD test pad; JLC Classification PCB
TP8: PWR_HOLD / GPIO12; TestPad_1.0mm; MPN SMD test pad; JLC Classification PCB
U1: USBLC6-2SC6; SOT-23-6; MPN USBLC6-2SC6; JLC/LCSC C7519
U2: CH340C; SOIC-16_3.9x9.9mm_P1.27mm; MPN CH340C; JLC/LCSC C7464026
U3: TP4056-42-ESOP8; SOIC-8-1EP_3.9x4.9mm_P1.27mm_EP2.41x3.3mm; MPN TP4056-42-ESOP8; JLC/LCSC C16581
U4: DW01A; SOT-23-6; MPN DW01A; JLC/LCSC C351410
U5: TPS63021DSJR; DFN-14-1EP_3x4mm_P0.5mm_EP1.7x3.3mm; MPN TPS63021DSJR; JLC/LCSC C202140
U6: ESP32-WROOM-32D-N16; ESP32-WROOM-32; MPN ESP32-WROOM-32D-N16; JLC/LCSC C529578
U7: MAX98357AETE+T; TQFN-16-1EP_3x3mm_P0.5mm_EP1.23x1.23mm; MPN MAX98357AETE+T; JLC/LCSC C910544
U8: Ra-01SH / SX1262 915MHz; Ai-Thinker_Ra-01SH; MPN Ra-01SH; JLC/LCSC C2764087

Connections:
/3V3: C10.1, C11.1, C12.1, C13.1, C15.1, C19.1, C27.1, C28.1, C29.1, C30.1, J5.1, J7.2, MK1.3, R5.1, R6.1, R15.1, R16.1, TP1.1, U2.4 (V3), U2.16 (VCC), U5.3, U5.4, U5.5, U6.2 (VDD), U8.3 (3V3)
/AMP_DATA: U6.36 (IO22), U7.1 (DIN)
/AMP_ENABLE: R20.1, U6.23 (IO15)
/AMP_SD: R19.1, R20.2, U7.4 (~SD_MODE)
/BAT_CELL: C6.1, J2.1, Q4.3 (D), R8.1, R13.1, U3.5 (BAT)
/BAT_SENSE: C14.1, R13.2, R14.1, U6.6 (IO34)
/BB_SW1: L1.1, U5.8, U5.9
/BB_SW2: L1.2, U5.6, U5.7
/BMS_CS: R9.1, U4.2 (CS)
/BMS_OC: Q3.4, U4.3 (OC)
/BMS_OD: Q3.6, U4.1 (OD)
/BMS_VCC: C7.1, R8.2, U4.5 (VCC)
/BTN1: SW1.1, U6.26 (IO4)
/BTN2: SW2.1, U6.16 (IO13)
/BTN3: SW3.1, U6.27 (IO16)
/BTN4: SW4.1, U6.12 (IO27)
/BTN5: D6.2 (A), U6.8 (IO32)
/BTN5_SW: D5.1 (K), D6.1 (K), SW5.1
/CC1: J1.A5 (CC1), R1.1
/CC2: J1.B5 (CC2), R2.1
/CELL_NEG: C7.2, J2.2, Q3.1, U4.6 (GND)
/CHG_LED_A: D3.2 (A), R25.2
/CHG_N: D3.1 (K), U3.7 (~CHRG)
/CHG_PROG: R7.1, U3.2 (PROG)
/DTR_N: Q2.2 (E), R22.1, U2.13 (~DTR)
/EN: C4.1, Q1.3 (C), R5.2, TP5.1, U6.3 (EN)
/GND: C1.2, C4.2, C5.2, C6.2, C8.2, C9.2, C10.2, C11.2, C12.2, C13.2, C14.2, C15.2, C16.2, C17.2, C18.2, C19.2, C20.2, C26.2, C27.2, C28.2, C29.2, C30.2, D2.1 (K), J1.A1 (GND), J1.A12 (GND), J1.B1 (GND), J1.B12 (GND), J1.SH (SHIELD), J5.3, J6.2, J7.1, MK1.1, MK1.2, MK1.4, Q3.3, Q6.2 (E), R1.2, R2.2, R7.2, R9.2, R10.2, R14.2, R19.2, R26.2, R28.2, SW1.2, SW2.2, SW3.2, SW4.2, SW5.2, TP2.1, U1.2 (GND), U2.1 (GND), U2.15 (R232), U3.1 (TEMP), U3.3 (GND), U3.9 (EPAD), U5.2, U5.13, U5.15, U6.1 (GND), U6.15 (GND), U6.38 (GND), U6.39 (GND), U7.2 (GAIN_SLOT), U7.3 (GND), U7.11 (GND), U7.15 (GND), U7.17 (PAD), U8.2 (GND), U8.9 (GND), U8.16 (GND)
/GPIO0: Q2.3 (C), R6.2, TP6.1, U6.25 (IO0)
/I2S_BCLK: MK1.6, U6.11 (IO26), U7.16 (BCLK)
/I2S_WS: MK1.5, U6.10 (IO25), U7.14 (LRCLK)
/LED+: J6.1, R21.2
/LED_STATUS: R21.1, R24.1, TP7.1, U6.24 (IO2)
/MIC_DATA: MK1.7, R26.1, U6.9 (IO33)
/OLED_SCL: J7.3, R16.2, U6.13 (IO14)
/OLED_SDA: J7.4, R15.2, U6.33 (IO21)
/POT_ADC: C26.1, J5.2, U6.7 (IO35)
/PROT_MID: Q3.2, Q3.5
/PWR_GATE: D5.2 (A), Q5.1 (G), Q6.3 (C), R27.2
/PWR_HOLD: R30.1, TP8.1, U6.14 (IO12)
/PWR_LATCH_BASE: Q6.1 (B), R28.1, R30.2
/Q1_BASE: Q1.1 (B), R22.2
/Q2_BASE: Q2.1 (B), R23.2
/RADIO_BUSY: U6.4 (SENSOR_VP), U8.10 (BUSY)
/RADIO_DIO1: U6.5 (SENSOR_VN), U8.6 (DIO1)
/RADIO_MISO: U6.31 (IO19), U8.13 (MISO)
/RADIO_MOSI: U6.37 (IO23), U8.14 (MOSI)
/RADIO_NSS: U6.29 (IO5), U8.15 (NSS)
/RADIO_RST: U6.28 (IO17), U8.4 (RESET)
/RADIO_SCK: U6.30 (IO18), U8.12 (SCK)
/RTS_N: Q1.2 (E), R23.1, U2.14 (~RTS)
/SPK+: J4.1, U7.9 (OUTP)
/SPK-: J4.2, U7.10 (OUTN)
/STATUS_LED_A: D2.2 (A), R24.2
/SYS_FUSED: F1.2, Q5.2 (S), R27.1
/SYS_RAW: D1.1 (K), F1.1, Q4.2 (S)
/SYS_SW: C8.1, C9.1, C16.1, C17.1, C18.1, C20.1, Q5.3 (D), U5.1, U5.10, U5.11, U5.12, U7.7 (VDD), U7.8 (VDD)
/UART_RX: TP4.1, U2.2 (TXD), U6.34 (RXD0/IO3)
/UART_TX: TP3.1, U2.3 (RXD), U6.35 (TXD0/IO1)
/USB_5V: C1.1, C5.1, D1.2 (A), J1.A4 (VBUS), J1.A9 (VBUS), J1.B4 (VBUS), J1.B9 (VBUS), Q4.1 (G), R10.1, R25.1, U1.5 (VBUS), U3.4 (V_{CC}), U3.8 (CE)
/USB_DM: R3.2, U2.6 (UD-)
/USB_DM_CONN: J1.A7 (D-), J1.B7 (D-), U1.3 (I/O2)
/USB_DM_ESD: R3.1, U1.4 (I/O2)
/USB_DP: R4.2, U2.5 (UD+)
/USB_DP_CONN: J1.A6 (D+), J1.B6 (D+), U1.1 (I/O1)
/USB_DP_ESD: R4.1, U1.6 (I/O1)

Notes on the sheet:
1–2 USB-C INPUT, CC SINK, AND ESD
3–4 CH340C USB-UART / AUTO PROGRAM
GPIO19/20 carry native USB D-/D+ through 22-ohm resistors. USB Serial/JTAG supports automatic download. VBUS is sensed through Q1 for self-powered USB-device firmware; this Type-C port remains a sink/device, not a host power source.
5 TP4056 CHARGER (~500 mA)
6 CELL PROTECTION (DW01A + FS8205A)
Overcurrent estimate: 150mV typical / (2×25mΩ) ≈3.0A at high gate; 150mV / (2×35mΩ) ≈2.14A at low gate. Tolerance/temp range is broader.
7–10 LOAD SHARE, PTC, SWITCH, 3.3 V BUCK-BOOST
USB present: D1 powers SYS_RAW and Q4 is off; TP4056 independently charges BAT_CELL. USB absent: Q4 body diode starts SYS_RAW then P-MOS turns on. Switch is downstream of charger. TPS63021 maintains 3.3V in buck/transition/boost; TI specifies 2A for VIN >2.5V. 2.2uH is sized for this <=1A rail.
11–12 ESP32-WROOM MODULE, ADC, AND SX1262 RADIO
BAT_SENSE uses ADC1 GPIO1; POT_ADC uses ADC1 GPIO2. 100k/100k gives 4.2V -> 2.1V; 21uA drain. Firmware: warn about 3.3V and orderly shutdown about 3.0-3.1V loaded; DW01 cutoff is backup only.
13–15 I2S MICROPHONE, CLASS-D AMP, SPEAKER
GAIN_SLOT tied directly to GND = +12dB. GPIO4 high enables left-channel audio; low shuts down. MAX98357A raw supply sees ≈3.0–4.2V battery or ≈4.7V from USB after SS34 (<5.5V max).
16 COMMERCIAL SSD1306 I2C OLED MODULE HEADER
Four through-hole connections only: pin 1 GND, pin 2 3V3, pin 3 SCL, pin 4 SDA. The commercial module supplies its own SSD1306 charge-pump parts; no raw SYS_SW reaches OLED logic.
17–20 POT, LED, 5× TWO-PIN BUTTONS, TEST PADS
Buttons: ESP32-S3 GPIO4/5/6/7/15 -> switch -> GND; firmware enables internal pull-ups. There are exactly 10 button holes, 3 pot holes, 2 LED holes, 4 OLED holes, and 2 power-switch holes.
SOFT POWER: hold BTN5 for 2 s. A press immediately wakes hardware; firmware must assert GPIO12/PWR_HOLD only after validating the full 2 s startup hold. While running, release PWR_HOLD after a 2 s shutdown hold; power drops when BTN5 is released. Typical OFF leakage target <2 uA; verify prototypes 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

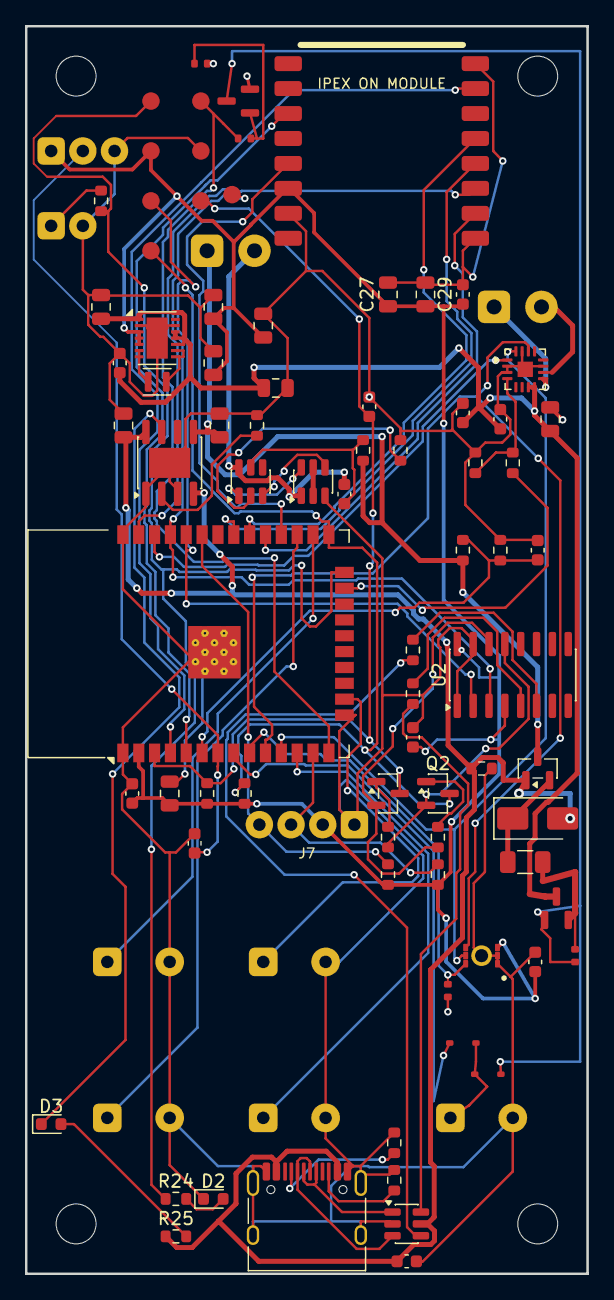
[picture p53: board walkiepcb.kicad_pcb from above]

Board: 2 copper layers, 45.0 x 100.0 mm, 93 parts (0 on the bottom side), 65 nets.

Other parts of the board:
H1, H2, H3, H4: MountingHole_3.2mm_M3

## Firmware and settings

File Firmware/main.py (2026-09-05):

from machine import Pin, SPI, I2S
from time import sleep_ms, ticks_ms, ticks_diff
from array import array

power = Pin(12, Pin.OUT)
power.value(1)

button = Pin(4, Pin.IN, Pin.PULL_UP)

amp = Pin(15, Pin.OUT)
amp.value(1)

nss = Pin(5, Pin.OUT)
reset = Pin(17, Pin.OUT)
busy = Pin(36, Pin.IN)

nss.value(1)

spi = SPI(
    2,
    baudrate=4000000,
    polarity=0,
    phase=0,
    sck=Pin(18),
    mosi=Pin(23),
    miso=Pin(19)
)

speaker = I2S(
    0,
    sck=Pin(26),
    ws=Pin(25),
    sd=Pin(22),
    mode=I2S.TX,
    bits=16,
    format=I2S.STEREO,
    rate=8000,
    ibuf=8000
)


def beep():
    sound = array("h")

    for i in range(1600):
        if i % 8 < 4:
            value = 8000
        else:
            value = -8000

        sound.append(value)
        sound.append(value)

    speaker.write(sound)


def wait_radio():
    while busy.value():
        sleep_ms(1)


def send_command(command, data=b""):
    wait_radio()

    nss.value(0)
    spi.write(bytes([command]) + data)
    nss.value(1)

    wait_radio()


def read_command(command, amount):
    wait_radio()

    nss.value(0)
    spi.write(bytes([command, 0]))
    data = spi.read(amount)
    nss.value(1)

    wait_radio()

    return data


def write_buffer(data):
    wait_radio()

    nss.value(0)
    spi.write(bytes([0x0E, 0]) + data)
    nss.value(1)

    wait_radio()


def read_buffer(start, amount):
    wait_radio()

    nss.value(0)
    spi.write(bytes([0x1E, start, 0]))
    data = spi.read(amount)
    nss.value(1)

    wait_radio()

    return data


def packet_size(size):
    send_command(
        0x8C,
        bytes([
            0, 8,
            0,
            size,
            1,
            0
        ])
    )


def clear_irq():
    send_command(0x02, b"\xFF\xFF")


def get_irq():
    data = read_command(0x12, 2)
    return (data[0] << 8) | data[1]


def receive_mode():
    send_command(0x80, b"\x00")
    packet_size(255)
    clear_irq()
    send_command(0x82, b"\xFF\xFF\xFF")


def setup_radio():
    reset.value(0)
    sleep_ms(10)

    reset.value(1)
    sleep_ms(20)

    send_command(0x80, b"\x00")
    send_command(0x96, b"\x00")
    send_command(0x9D, b"\x01")
    send_command(0x8A, b"\x01")
    send_command(0x98, b"\xE1\xE9")

    frequency = 915000000
    number = frequency * (1 << 25) // 32000000

    send_command(
        0x86,
        bytes([
            (number >> 24) & 255,
            (number >> 16) & 255,
            (number >> 8) & 255,
            number & 255
        ])
    )

    send_command(0x8B, b"\x07\x04\x01\x00")
    send_command(0x95, b"\x04\x07\x00\x01")
    send_command(0x8E, b"\x0A\x04")
    send_command(0x8F, b"\x00\x00")

    receive_mode()


def send_signal():
    message = b"BEEP"

    send_command(0x80, b"\x00")
    clear_irq()

    write_buffer(message)
    packet_size(len(message))

    send_command(0x83, b"\x00\x00\x00")

    start = ticks_ms()

    while not get_irq() & 1:
        if ticks_diff(ticks_ms(), start) > 2000:
            break

        sleep_ms(5)

    print("Signal sent")

    receive_mode()


def check_radio():
    irq = get_irq()

    if irq & 2:
        info = read_command(0x13, 2)

        size = info[0]
        start = info[1]

        message = read_buffer(start, size)

        receive_mode()

        if message == b"BEEP":
            print("Signal received")
            beep()


setup_radio()

print("Ready")

last_button = 1

while True:
    check_radio()

    current_button = button.value()

    if current_button == 0 and last_button == 1:
        send_signal()

    last_button = current_button

    sleep_ms(10)

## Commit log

2026-08-30 Finalize BTN5 soft power PCB release
    [bom.csv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]
2026-08-30 Reorganize assets and keep local tooling private
    [walkiepcb_final_exact_usb.step]
2026-08-31 Fix JLC placement coordinate system
    [walkiepcb-B_Cu.gbl, walkiepcb-B_Mask.gbs, walkiepcb-B_Paste.gbp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]
2026-09-02 Add journal entries with images and case design timelapse
